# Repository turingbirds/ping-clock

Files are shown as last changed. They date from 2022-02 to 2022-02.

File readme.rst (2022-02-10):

The Ping Clock
==============

Are you ever in a video call, when the other party suddenly freezes mid-sentence, leaving you wondering after a few seconds of silence: is it my connection that's having issues, or theirs? In such situations, one glance at the ping clock dial provides an immediate overview of your internet connection status and health, measured in terms of ping time.

Ping time is the time it takes for a network packet to reach a certain destination host and come back again. Lower is better; for video calls, anything below a few tenths of a second is typically fine. The host can be chosen as a public server with high reliability (for example, google.com or 80.80.80.80), or as something with a special significance (like the hostname of your cloud instance).

If your video call freezes, but the ping clock continues to indicate low ping, there is no need to reset your router; just wait for the other side to come back.

.. table::
   :align: center

   +-------------------------------------------------------------------------------------------------------------------------------------------------------------+
   | 🢧  `Click here for a video of the ping clock in action <https://github.com/turingbirds/ping-clock/blob/master/fig/ping_clock_movie.mp4?raw=true>`_        🢠 |
   +-------------------------------------------------------------------------------------------------------------------------------------------------------------+

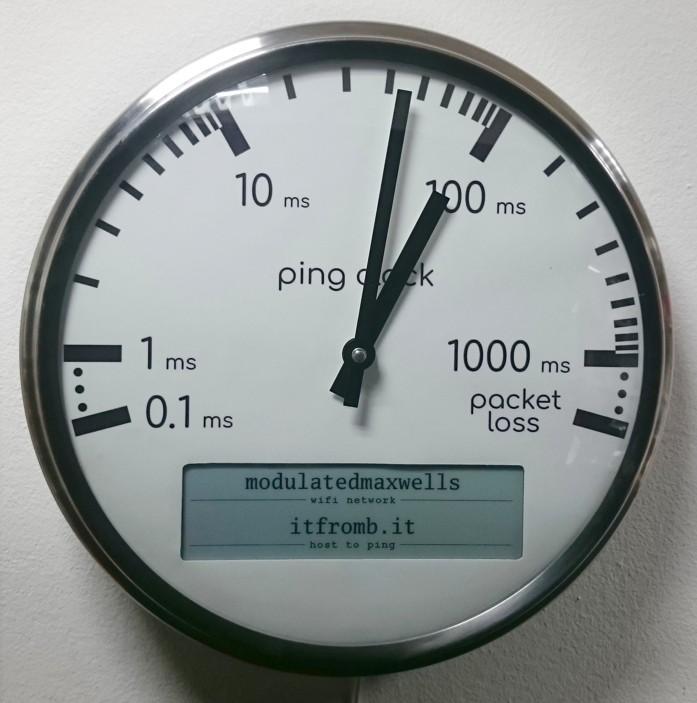
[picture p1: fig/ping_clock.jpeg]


Setting up the wifi network and host to ping is done by connecting to the ping clock's wifi access point. After configuration, the outermost hand will update once each second with the latest ping value, while the innermost hand tracks the recent maximum pings, making an intermittent connection easy to see.





.. table::
   :align: center

   +---------------+---------------+
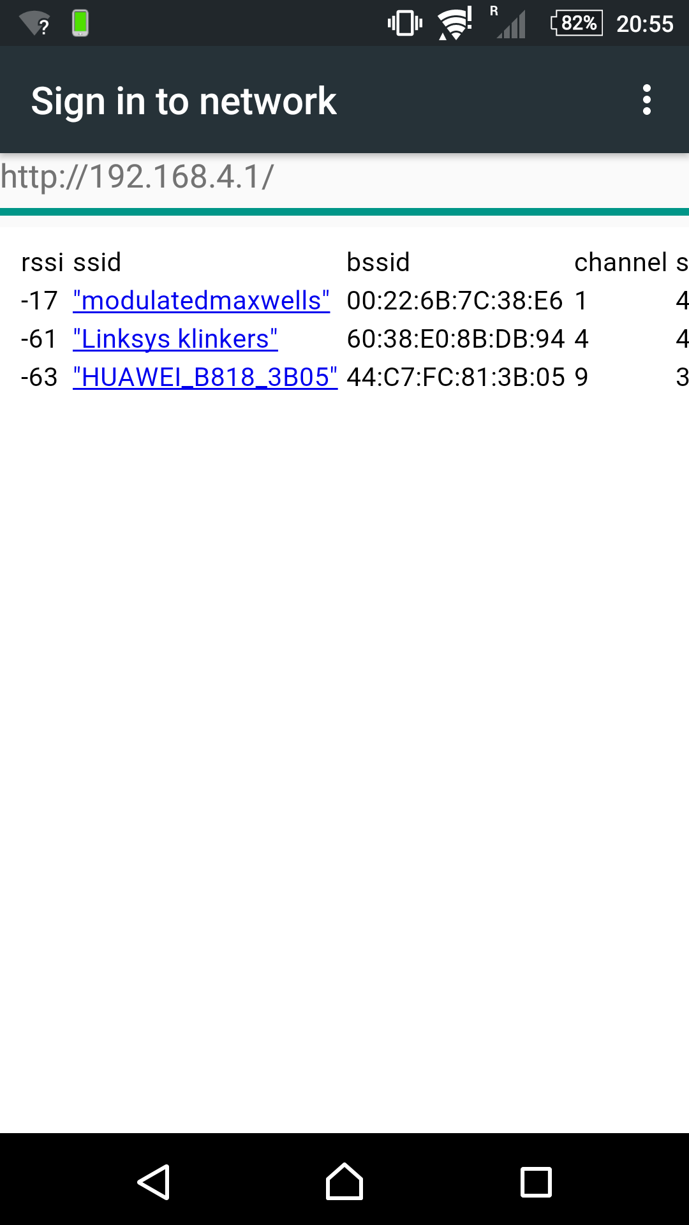
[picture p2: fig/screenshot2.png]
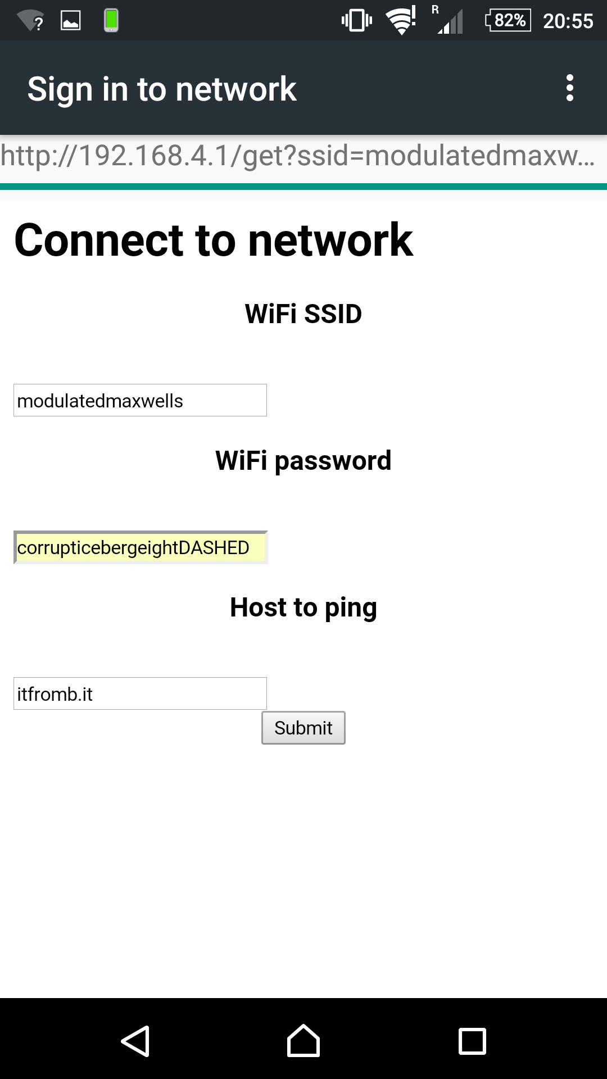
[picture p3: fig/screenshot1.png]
   |  |  |
   +---------------+---------------+

Hardware
--------

The system is controlled by an ESP32, which connects via wifi and updates the e-paper display, and then performs the ping, computes the desired clock hand angles, and sends this angle via SPI to a second ESP32, which functions exclusively as a motor controller.

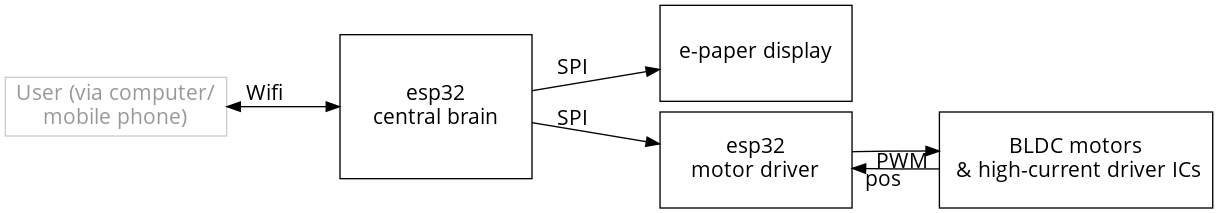
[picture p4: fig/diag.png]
System block diagram


For mounting the components to the frontplate, a template is provided in `frontplate-cad/frontplate_cnc.pdf <https://github.com/turingbirds/ping-clock/blob/master/frontplate-cad/frontplate_cnc.pdf>`_. Drill out all the holes marked in pink, then drill out all the M3 screw holes at half depth in a larger diameter, to create holes for the countersunk screw heads. The frontplate decal then lies flat against the front, covering all the screws. The front of the e-paper display is pressed against the back of the faceplace, held in place by two aluminium bars covered in a layer of foam.
   
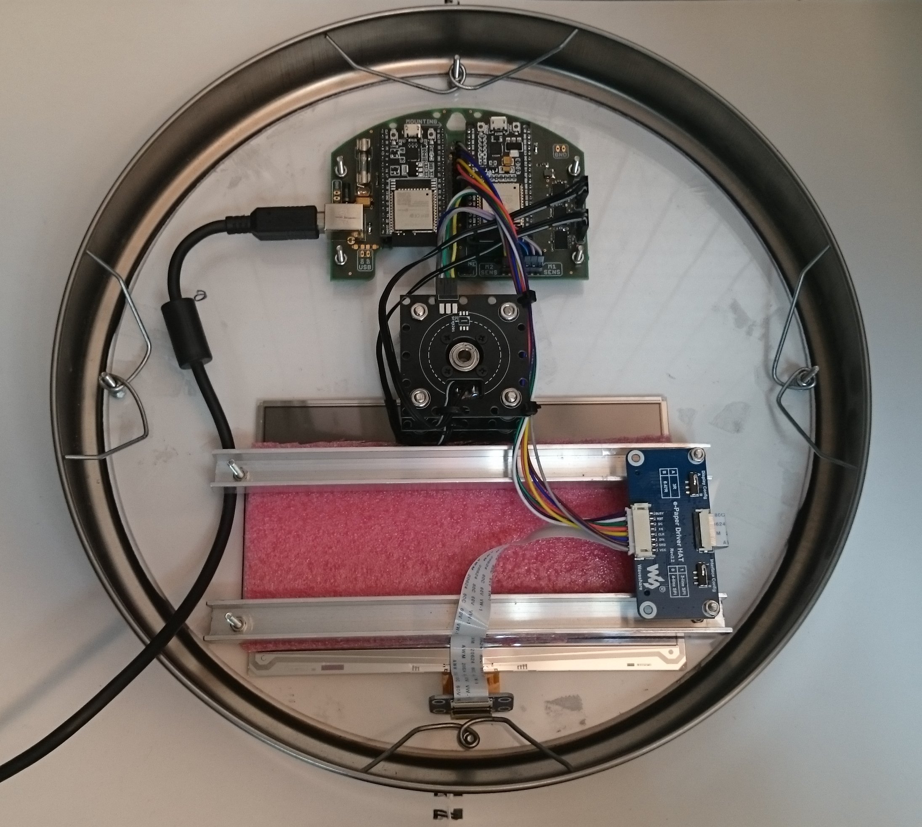
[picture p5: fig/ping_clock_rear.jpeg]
Rear view of the ping clock


The clock is powered from a 5 V DC supply, and consumes approximately 2 W of power. The ESP32s and motor driver ICs are mounted on a custom PCB (see `pcb/ping_clock_mounting_pcb.* <pcb/>`_). 

Dual clock hands motor module
~~~~~~~~~~~~~~~~~~~~~~~~~~~~~

Each hand is actuated by a three-phase brushless DC (BLDC) motor. Actuation is 'direct drive': the hands are mounted directly onto the rotating surface of the motors via two 3D printed hubs.

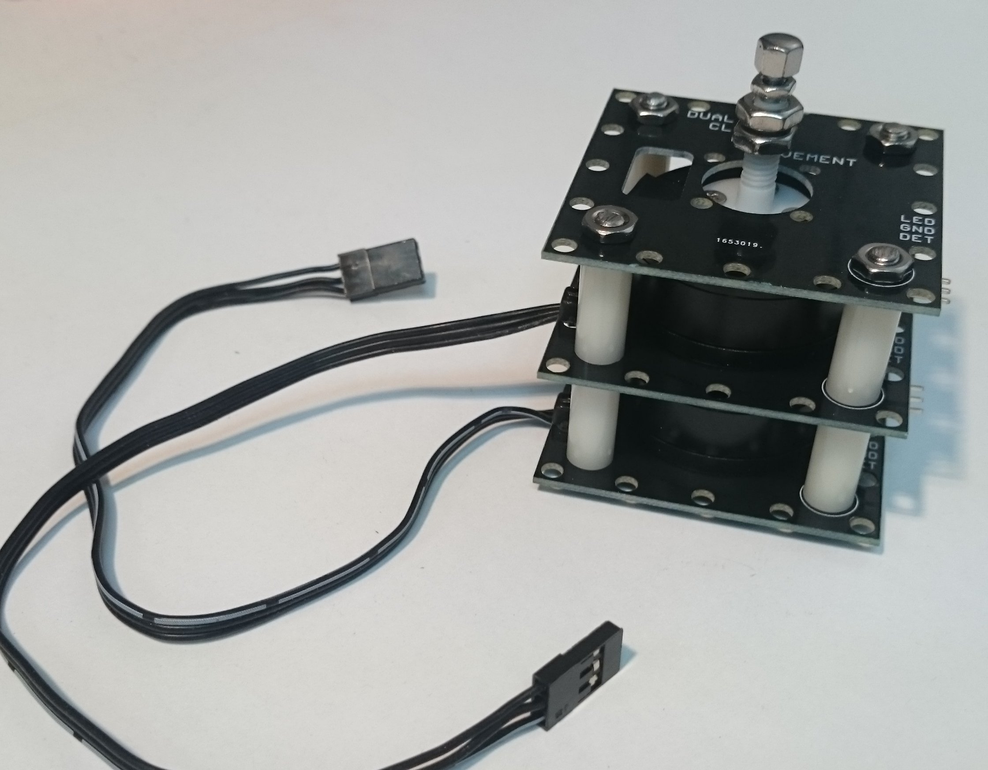
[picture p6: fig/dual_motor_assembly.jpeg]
The dual motor assembly by itself


BLDC motors can be easily controlled as open-loop servos (akin to stepper motors), with reliable tracking over long timescales provided that the load torque is minimal and that acceleration is bounded. An optical reflection light sensor provides an absolute reference point or 'zero angle'. The motor controller ESP32 generates three-channel PWM drive signals for each motor, following a trapezoidal commutation scheme.

PCBs are 1.2 mm, with black solder mask to reduce ambient light for the optical sensors. All three PCBs (`pcb/motor_module_pcb.* <pcb/>`_) are identical, but only two of them need to have a reflection sensor mounted. The dimensions (width x depth x height) of the assembly, ignoring the protruding hubs, is 50 x 50 x 44 mm. The height is 2 * 18 (spacers) + 3 * 1.2 (PCBs) + 2 * 2.2 (thin M4 nuts) = 44 mm.

Hubs
~~~~

The hubs can be 3D printed using the stereolithographic (resin/UV) method. The outer hub is shown first and contains an outer M5 thread to facilitate mounting the corresponding hand. It has a hollow core, which allows the threaded rod of the inner hand assembly to pass through.

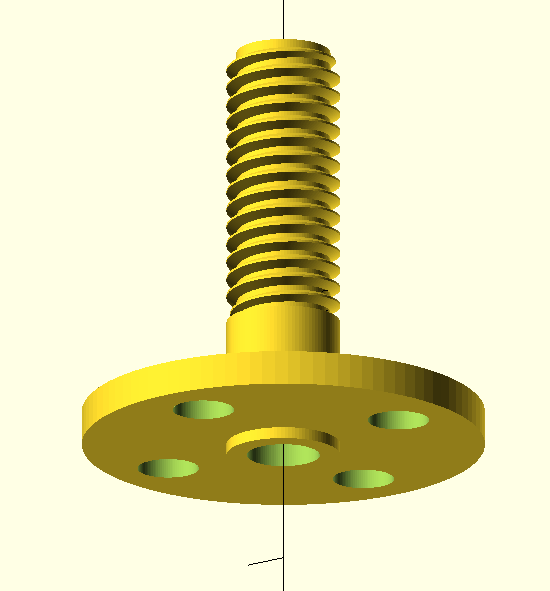
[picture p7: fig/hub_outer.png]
3D view of the outer hub in OpenSCAD


The inner hub provides an inner M3 thread, that seats a short section of threaded rod, which sticks through the other hub and to the front of the clock faceplate.

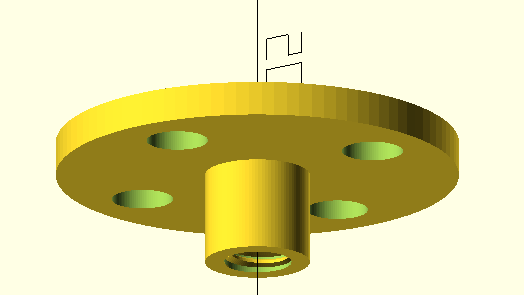
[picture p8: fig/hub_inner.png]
3D view of the inner hub in OpenSCAD


The hands are mounted using the threads provided:

- Central axis: M3 (3 mm diameter) threaded rod

  The hand is pressed between a thin M3 nut and an M3 capped nut.

- Hub axis: M5 (5 mm diameter), threaded
  
  The hand is pressed between two thin M5 nuts. A single M5 rivet could potentially also be used, extending into the clock, to reduce the height that is necessary above the faceplate.

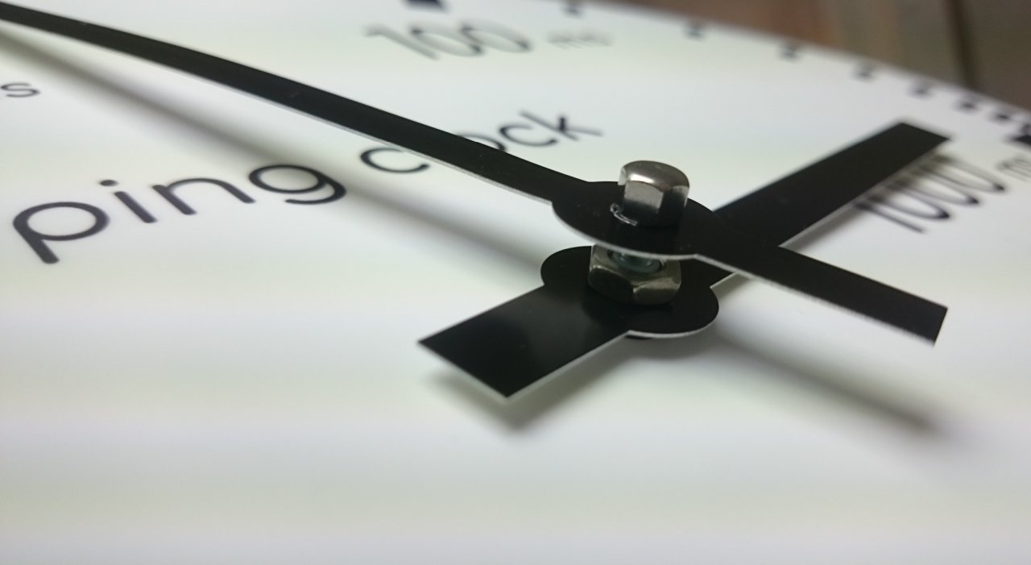
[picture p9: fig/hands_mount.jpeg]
Mounting the clock hands


It is advisable to post-process the 3D printed threads by going over the threads with an M3 and M5 tap, and to drill out the hollow core on the outer hub using a 3.2 mm drill.

Frontplate
~~~~~~~~~~

The frontplate is made out of polycarbonate, in a circular shape, thickness = 4 mm, diameter = 275 (visible portion) + 2*7.5 (behind the metal rim on either side) = 290 mm.

The frontplate graphics can be printed on A3 size paper. A better alternative is to get it as a vinyl sticker.

Note that not all of the display pixels are visible with the current cutout dimensions. This is by design, but you can make the cutout larger to reveal a larger area of the display.

Rim
~~~

Reused from Ikea clock, diameter = 275 mm (dial), 300 mm (overall).

Bill of materials
-----------------

Hardware
~~~~~~~~

(shipping costs excluded)

.. csv-table:: Bill of materials
   :header: "€", "Description"

   "57.19", "7.5"", 800x480 pixel e-paper display https://www.waveshare.com/w/upload/6/60/7.5inch_e-Paper_V2_Specification.pdf"
   "14.92", "Frontplate https://kunststofplatenshop.nl/product/polycarbonaat-helder-4-mm/"
   "6.20", "TB6612FNG motor driver IC (qty: 3)"
   "4", "SFH9201 optical sensor (qty: 2)"
   "7.71", "motor assembly PCBs, color: black, thickness: 1.2mm (seeedstudio; qty: 3)"
   "1.66", "3D printing of the hubs (dirtypcbs.com)"
   "5", "System PCB, color: any, thickness: 1.6 mm (seeedstudio)"
   "14", "frontplate laser-cut vinyl sticker (note: printing this on A3 size paper and cutting it out by hand is a cheaper alternative)"
   "0.10", "motor position sticker (qty: 2)"
   "1", "screws 2mm flat head (qty: 8)"
   "1", "screws 2.5mm flat head (qty: 8)"
   "1", "screws 3mm countersunk head (qty: 16)"
   "1", "M3 nut (qty: 36)"
   "1", "thin M4 nut (qty: 8)"
   "0.50", "M3 threaded rod"
   "1", "M4 threaded rod"
   "0.10", "thin M5 nut (qty: 2)"
   "0.10", "thin M3 nut"
   "0.10", "M3 capped nut"
   "0.55", "vinyl spacer, h = 18 mm, inner d = 4 mm, outer d = 7 mm (qty: 8)"
   "13.69", "BLDC motor with hollow axis (qty: 2)"
   "7.14", "ESP32-DEVKIT (qty: 2)"
   "1", "USB-A PCB mount connector"
   "1", "500 mA fuse and holder"
   "1", "0.1"" IDC headers"
   "1", "0.1"" IDC cables"
   "0.10", "470 R resistor 1206 (qty: 3)"
   "0.10", "47k R resistor 1206 (qty: 2)"
   "0.10", "100 nF capacitor 1206 (qty: 10)"
   "0.10", "10 uF tantal capacitor SMD"
   "5", "Ikea clock (second hand, for the rim and glass)"
   "", ""
   "148.36", "**Total**"

Software
~~~~~~~~

Comfortaa font <aajohan@gmail.com> SIL Open Font License, Version 1.1

Luxi font copyright (c) 2001 by Bigelow & Holmes Inc.

Ping code from https://github.com/marian-craciunescu/ESP32Ping (LGPL-2.1 license).

log2fix code from https://github.com/dmoulding/log2fix (MIT license).

Credits
-------

With gratitude to `Jan Breemer <http://www.breem.nl/>`_ for debugging the 3D model of the hubs and help with the prototype!

License
-------

`Open source hardware <https://www.oshwa.org/>`_ is hardware for which the design is made publicly available, so that anyone can study, modify, distribute, make, and sell the design or hardware based on that design, subject to the following license conditions.

Hardware licensed under the *CERN Open Hardware Licence Version 2 - Weakly Reciprocal,* a copy of which is included in this repository at `cern_ohl_w_v2.txt <https://github.com/turingbirds/ping-clock/blob/master/cern_ohl_w_v2.txt>`_.

Software licensed under the *Apache License 2.0,* a copy of which is included at `apache_license_2.0.txt <https://github.com/turingbirds/ping-clock/blob/master/apache_license_2.0.txt>`_.

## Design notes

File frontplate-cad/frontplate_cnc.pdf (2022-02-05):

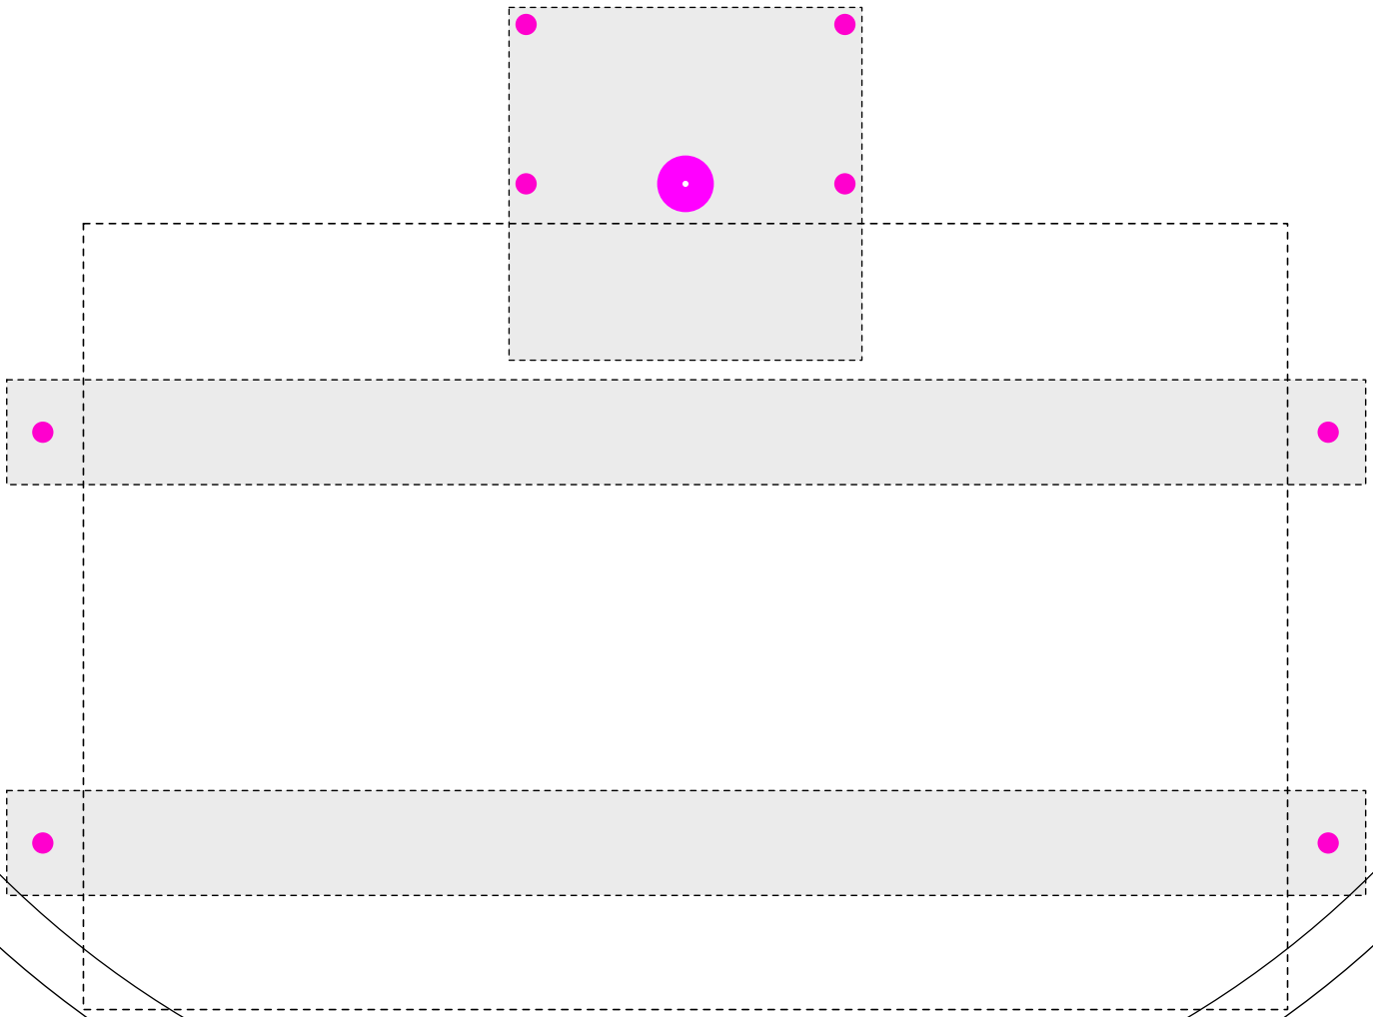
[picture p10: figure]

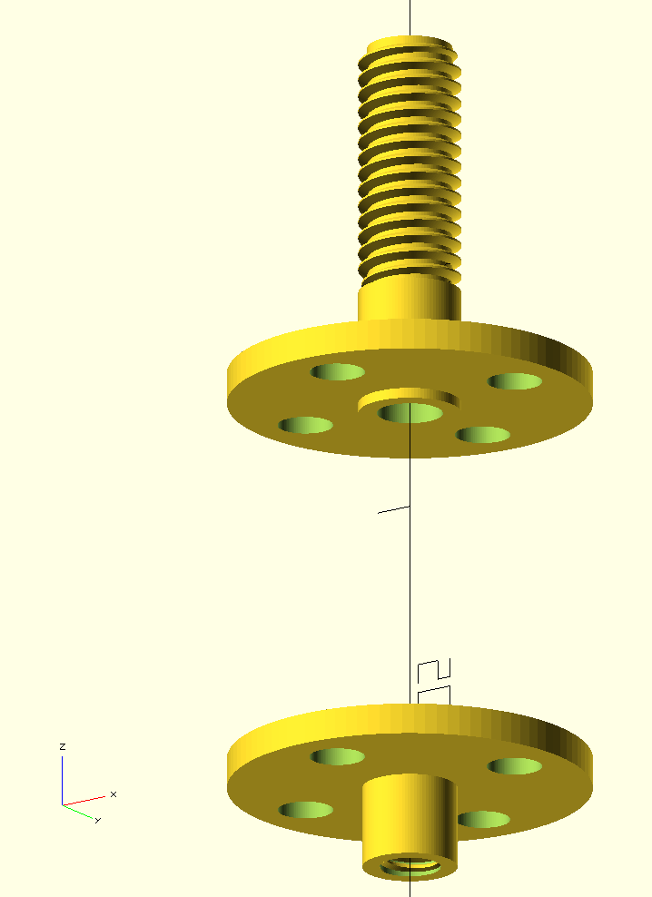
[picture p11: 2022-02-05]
fig/hubs.png

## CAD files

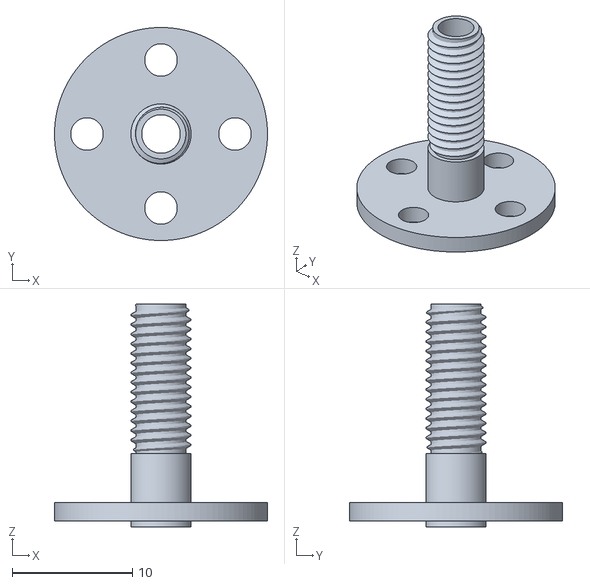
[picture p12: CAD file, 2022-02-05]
dual_bldc_assembly/outer_hub.stl
17.7 x 17.7 x 18.5

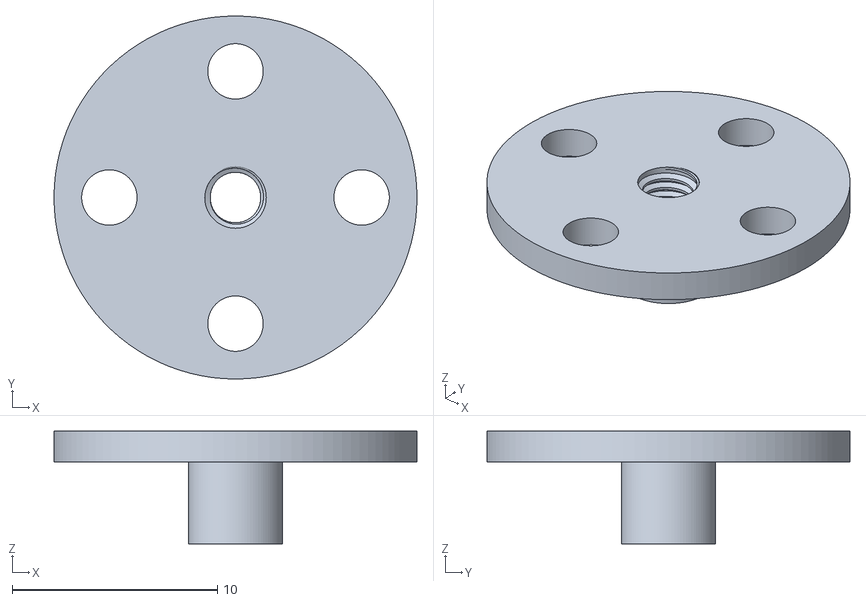
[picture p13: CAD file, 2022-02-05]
dual_bldc_assembly/inner_hub.stl
17.7 x 17.7 x 5.50

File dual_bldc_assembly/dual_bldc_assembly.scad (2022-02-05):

/**

Charl Linssen <charl@itfromb.it>, December 2021

Inner hub needs to tapped internally at M3 to accept threaded rod. Rod is secured to the hub by one additional nut on top of the hub (towards the front of the clock face).

Outer hub needs to be tapped externally (at the front of the clock) at M5 to allow clock hand to be mounted (clamped between two thin M5 nuts).

**/

include <NopSCADlib/core.scad>
use <NopSCADlib/utils/thread.scad>


/**
 * OpenSCAD rendering parameters
**/

pi = 3.14159;

quality_factor = 10;

$fn = quality_factor * 10;
$fn2 = quality_factor * 10;

bevel_resolution = quality_factor;


/**
 * which parts to draw (set to 0 or 1)
**/

draw_motors = 0;
draw_mounting = 0;


/**
 * margins
**/

epsilon = .1; // [mm]
motor_axis_insert_margin = .1; // [mm]


/**
 * model parameters for BLDC motors
**/

r_eccentr_holes_bldc_stator = 19.1/2;  // [mm]
r_eccentr_holes_bldc_rotor = 12.3/2;  // [mm]
n_holes_bldc_stator = 4;
deg_per_hole = 360/n_holes_bldc_stator;
D_bldc_motor = 34.56; // diameter of the motor itself [mm]
h_bldc_motor = 14.22; // height of the motor itself [mm]
D_bldc_motor_cutout = 5; // diameter of the hollow axis of the BLDC motor [mm]
D_bldc_rotor_cutout = 15;  // cutout of the mounting plane for the rotor+hub to pass through [mm]


/**
 * model parameters for the hubs
**/

hub_base_thickness = 1.5; // [mm]
D_bldc_stator_holes = 2.7;   // diameter of the holes for mounting it to the motor [mm] (screw thread is M2.5)

h_outer_hub = 18; // [mm]
D_outer_hub_outer = 5; // diameter of the outer clock hand [mm]

h_inner_hub = 37; // [mm]
D_inner_hub_outer = 3; // diameter of the inner clock hand [mm]

inner_hub_h_motor_insert = 4; // length by which the rear end of the rotating plate sticks into the motor
outer_hub_h_motor_insert = .5; // length by which the rear end of the rotating plate sticks into the motor

outer_hub_thread_height = 12.5;


/**
 * model parameters for mounting plane standoffs
**/

h_standoffs = 18; // [mm]

D_standoffs_inner = 4; // [mm]
D_standoffs_outer = 7; // [mm]
r_ecc_standoffs = 25; // [mm]

h_thin_M4_nut = 2.1;  // [mm]
r_hub_cutout = 15/2; // [mm] XXX: was 4

z_second_platform = hub_base_thickness + h_standoffs;


// ----------------------------------------------------------------------------------------------------


/**
 * inner hub
**/

color([.5, .7, .7])
translate([0., 0., hub_base_thickness + h_bldc_motor])
union() {
    // base
    difference() {
        union() {
            cylinder(h=hub_base_thickness, r=r_eccentr_holes_bldc_rotor + D_bldc_stator_holes);

            // part that sticks out the back
            translate([0,0,-inner_hub_h_motor_insert])
            cylinder(h=inner_hub_h_motor_insert + epsilon, r=D_bldc_motor_cutout/2 - motor_axis_insert_margin);
        }
        
        union() {
            translate([0, 0, -inner_hub_h_motor_insert - epsilon])
            cylinder(h=inner_hub_h_motor_insert + h_inner_hub + 2*epsilon, r=D_inner_hub_outer/2 + 2*epsilon);   // XXX: slight bit of extra cutout for the thread

            // holes for rotor mounting screws
            for (hole_idx = [0:(n_holes_bldc_stator-1)]) {
                rotate(a=hole_idx * deg_per_hole, v=[0, 0, 1])
                translate([0., r_eccentr_holes_bldc_rotor, -epsilon])
                cylinder(h=hub_base_thickness + 2*epsilon, r=D_bldc_stator_holes/2);
            }
        }
    }
    translate([0, 0, -inner_hub_h_motor_insert+ (inner_hub_h_motor_insert + hub_base_thickness) / 2])
    female_metric_thread(3, metric_coarse_pitch(3), inner_hub_h_motor_insert + hub_base_thickness);
}


/**
 * outer hub
**/

color([.3, .5, .7])
translate([0., 0., z_second_platform + hub_base_thickness + h_bldc_motor])
difference() {
    union() {
        cylinder(h=h_outer_hub, r=D_outer_hub_outer/2 - .43);

        intersection() {
            difference() {
                translate([0., 0., outer_hub_thread_height/2 + h_outer_hub - outer_hub_thread_height])
                male_metric_thread(5, metric_coarse_pitch(5), outer_hub_thread_height);
        
                cylinder(h=h_outer_hub, r=D_outer_hub_outer/2 - .43 - 2 * epsilon);
            }
            cylinder(h=h_outer_hub, r=D_outer_hub_outer*2);
        }

        cylinder(h=h_outer_hub - outer_hub_thread_height + epsilon, r=D_outer_hub_outer/2);

        // part that sticks out the back
        translate([0,0,-outer_hub_h_motor_insert])
        cylinder(h=outer_hub_h_motor_insert + epsilon, r=D_bldc_motor_cutout/2 - motor_axis_insert_margin);
       
        // base
        difference() {
            cylinder(h=hub_base_thickness, r=r_eccentr_holes_bldc_rotor + D_bldc_stator_holes);

            union() {
                // holes for rotor mounting screws
                for (hole_idx = [0:(n_holes_bldc_stator-1)]) {
                    rotate(a=hole_idx * deg_per_hole, v=[0, 0, 1])
                    translate([0., r_eccentr_holes_bldc_rotor, -epsilon])
                    cylinder(h=hub_base_thickness + 2*epsilon, r=D_bldc_stator_holes/2);
                }
            }
        }

        if (draw_mounting) {
            /**
             * mounting screw heads
            **/

            for (hole_idx = [0:(n_holes_bldc_stator-1)]) {
                rotate(a=hole_idx * deg_per_hole, v=[0, 0, 1])
                translate([0., r_eccentr_holes_bldc_rotor, hub_base_thickness+.02])
                cylinder(h=1, r=2); // screw head height: 1mm, dia: 4mm
            }
        }
    }

    // cutout for the inner hub
    translate([0, 0, -h_outer_hub])
    cylinder(h=3*h_outer_hub, r=D_inner_hub_outer/2 + epsilon);
}

    
/**
 * PCBs, mounting, screws, etc.
**/

if (draw_mounting) {

    /**
     * mounting planes for BLDCs
    **/

    for (motor_idx = [0:2]) {
        translate([0., 0, motor_idx*z_second_platform])
        difference() {
            translate([0, 0, hub_base_thickness/2])
            cube([50,50,hub_base_thickness], center=true);

            union() {
                if (motor_idx < 2) {
                    // holes for mounting screws
                    for (hole_idx = [0:(n_holes_bldc_stator-1)]) {
                        rotate(a=hole_idx * deg_per_hole, v=[0, 0, 1])
                        translate([0., r_eccentr_holes_bldc_stator, -epsilon])
                        cylinder(h=hub_base_thickness + 2*epsilon, r=D_bldc_stator_holes/2);
                    }
                    // central rotor cutout hole
                    translate([0., 0., -epsilon])
                    cylinder(h=hub_base_thickness + 2*epsilon, r=D_bldc_rotor_cutout/2);
                }
                else {
                    // central rotor cutout hole
                translate([0., 0., -epsilon])
                cylinder(h=hub_base_thickness + 2*epsilon, r=r_hub_cutout);
                }
            }
        }
    }

        // mounting screw heads
        for (hole_idx = [0:(n_holes_bldc_stator-1)]) {
            rotate(a=hole_idx * deg_per_hole, v=[0, 0, 1])
            translate([0., r_eccentr_holes_bldc_stator, hub_base_thickness+.1])
    translate([0., 0, 2*z_second_platform-2.62])
            cylinder(h=1, r=2); // screw head height: 1mm, dia: 4mm
        }


    /**
     *  holes for mounting screws
    **/

    %
    for (z = [0:z_second_platform]) {
        for (hole_idx = [0:(n_holes_bldc_stator-1)]) {
            rotate(a=hole_idx * deg_per_hole + 45, v=[0, 0, 1])
            translate([0., -r_ecc_standoffs, z + hub_base_thickness])
            cylinder(h=h_standoffs, r=D_standoffs_outer/2);
        }
    }

    /**
     *  photo switches
    **/

    h_photo_switch = 2.1;

    rotate(a=45, v=[0, 0, 1])
    union() {
        translate([-12.5, 0, 37.5])
        cube([3.4, 4.2, h_photo_switch], center=true);

        translate([0., 0, z_second_platform])
        translate([-12.5, 0, -h_photo_switch/2 - .1])
        cube([3.4, 4.2, h_photo_switch], center=true);
    };
}

/**
 * BLDC motors 
**/

if (draw_motors) {
    for (motor_idx = [0:1]) {
        translate([0., 0, hub_base_thickness + motor_idx*z_second_platform])
        difference() {
        color([1,0,0],.2)
            cylinder(h=h_bldc_motor, r=D_bldc_motor/2);
             
            translate([0., 0, -epsilon])
            cylinder(h=h_bldc_motor + 2*epsilon, r=D_bldc_motor_cutout/2);
        }
    }
}

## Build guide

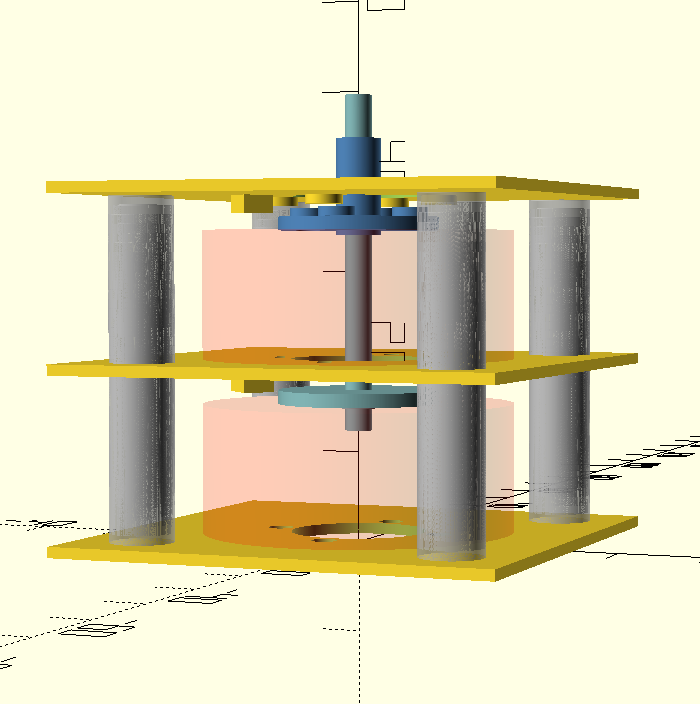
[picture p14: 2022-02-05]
fig/dual_motor_assembly.png

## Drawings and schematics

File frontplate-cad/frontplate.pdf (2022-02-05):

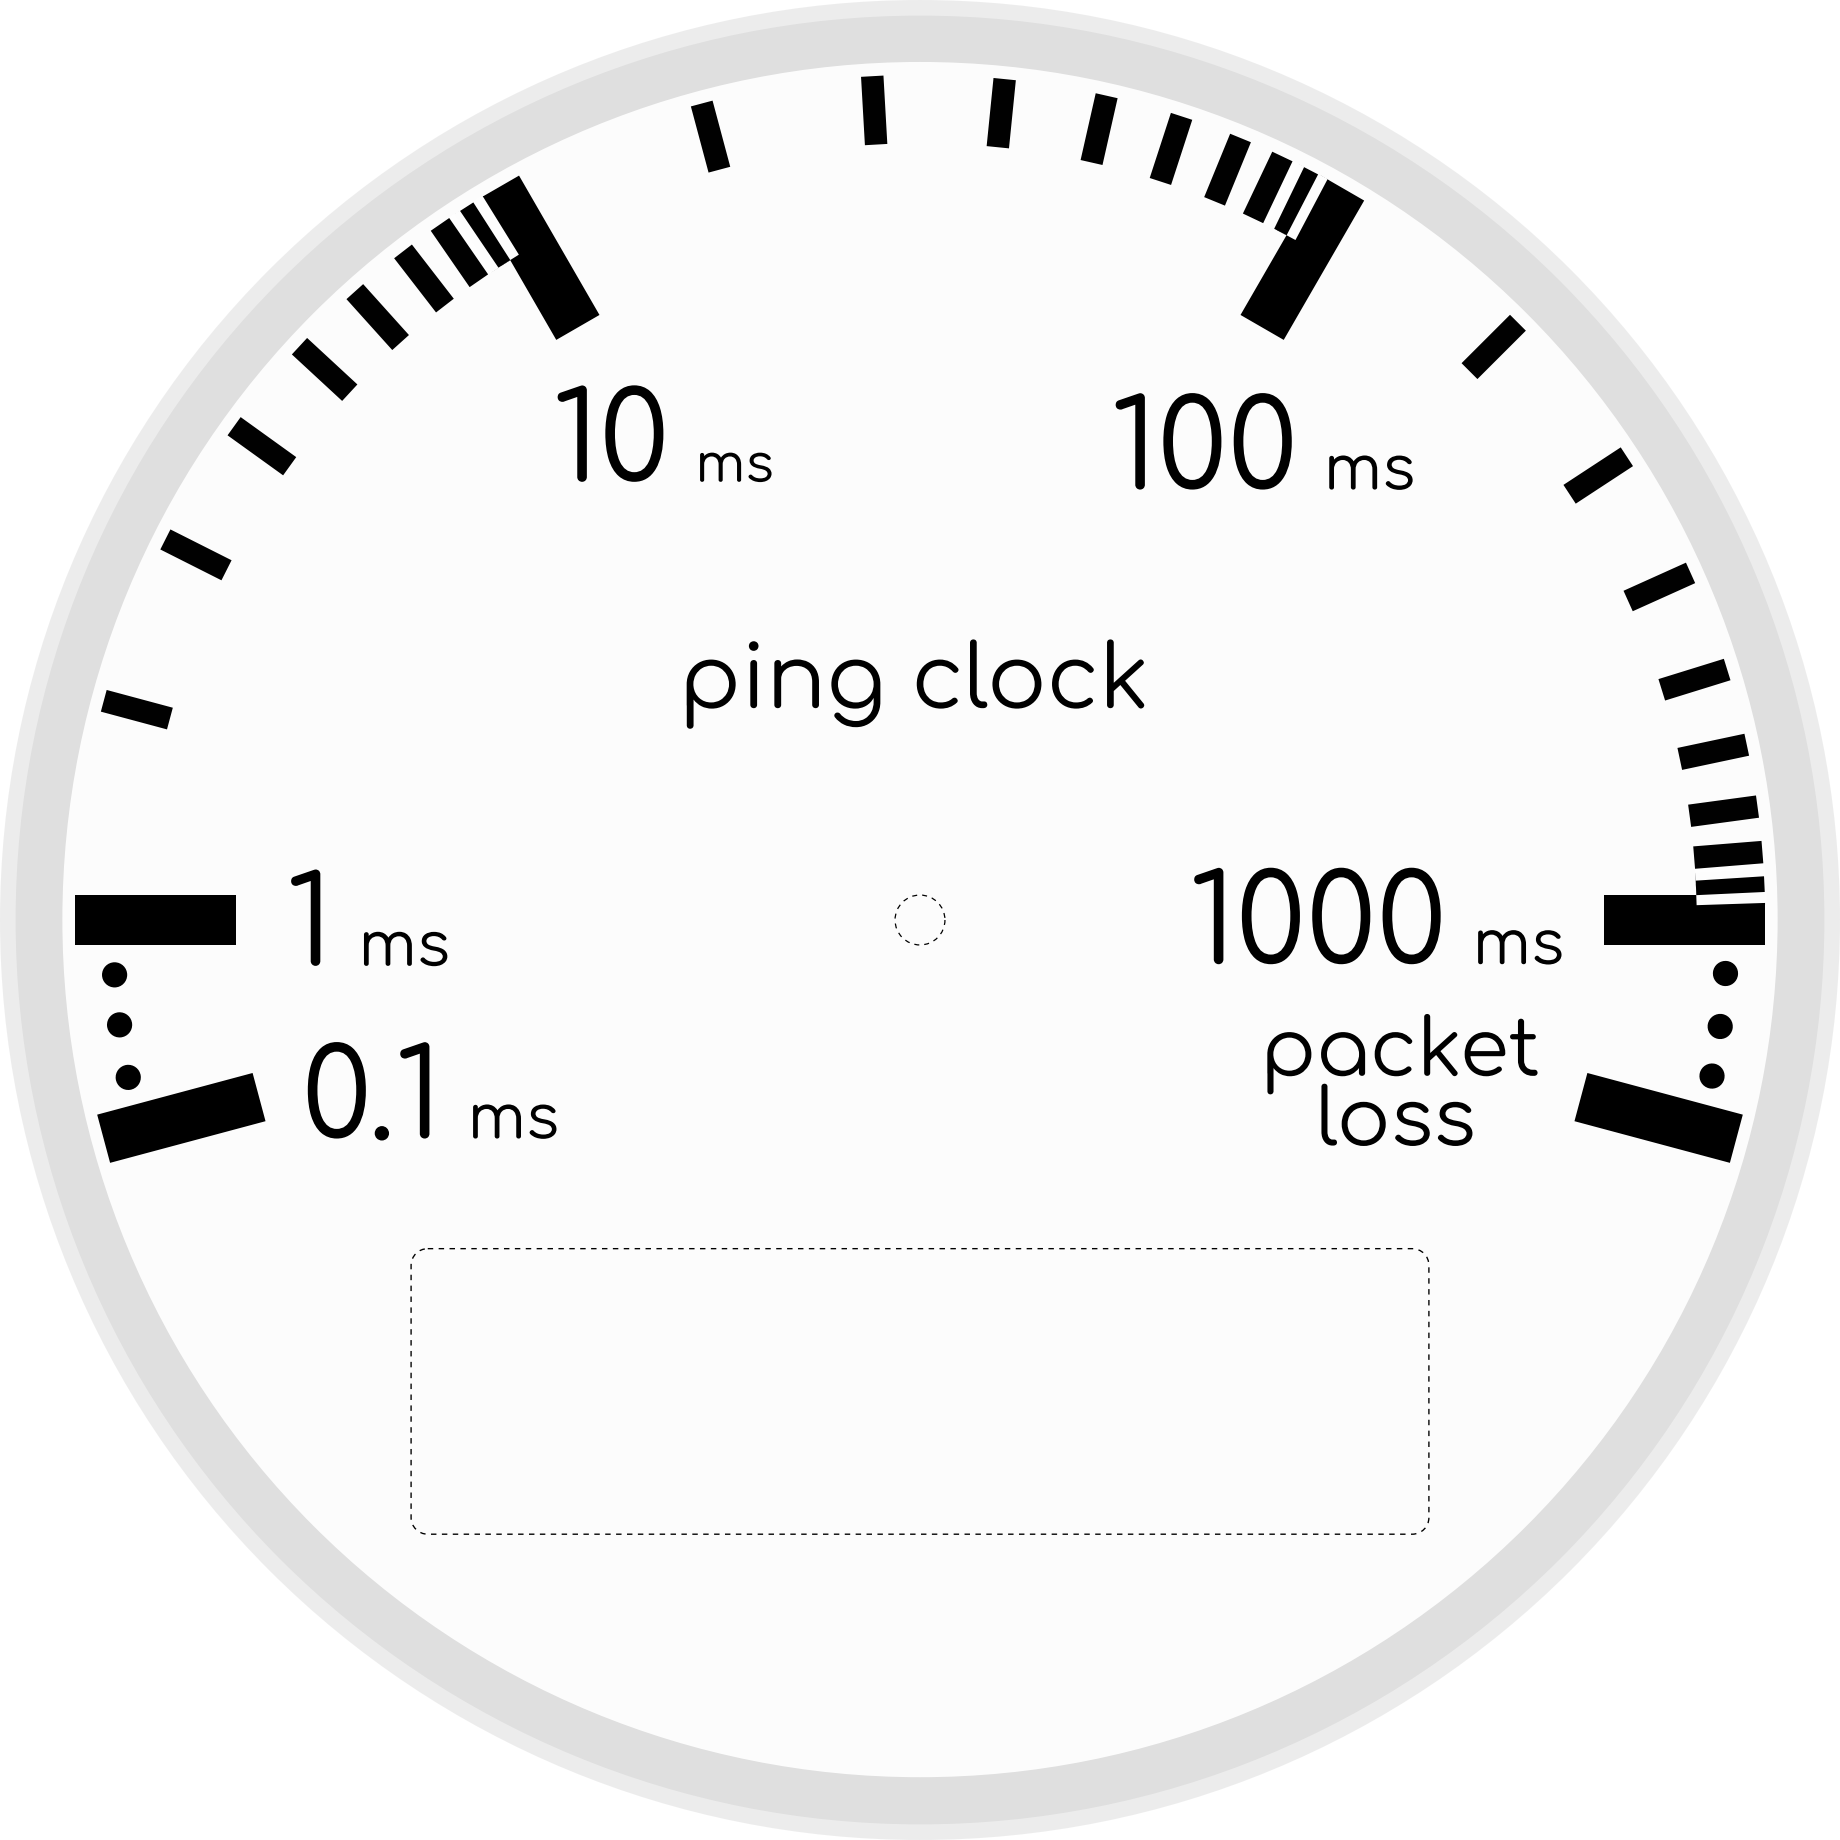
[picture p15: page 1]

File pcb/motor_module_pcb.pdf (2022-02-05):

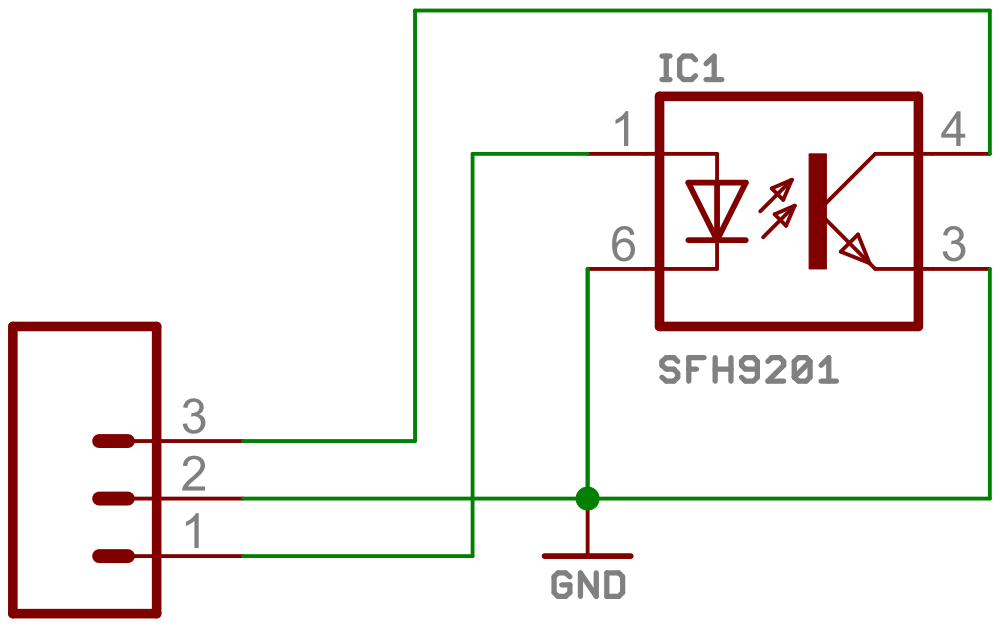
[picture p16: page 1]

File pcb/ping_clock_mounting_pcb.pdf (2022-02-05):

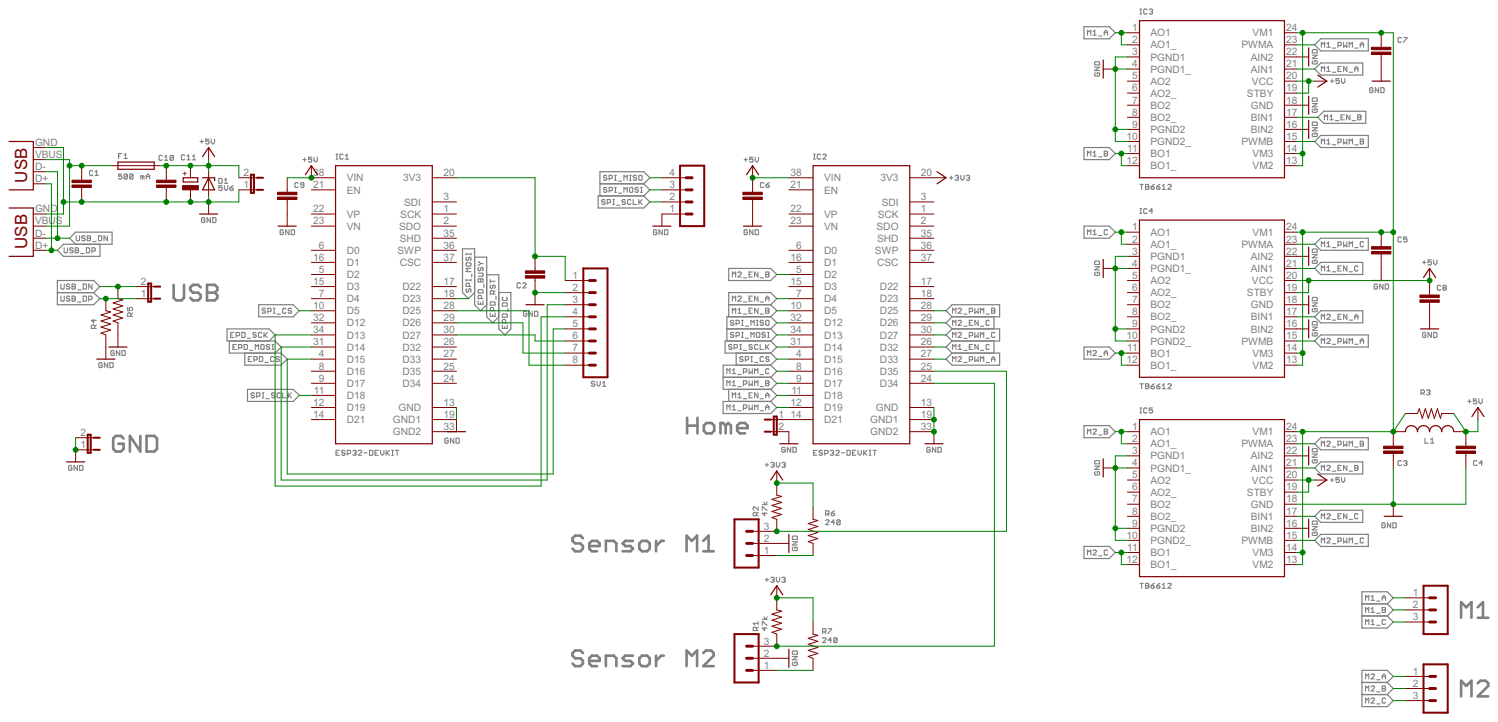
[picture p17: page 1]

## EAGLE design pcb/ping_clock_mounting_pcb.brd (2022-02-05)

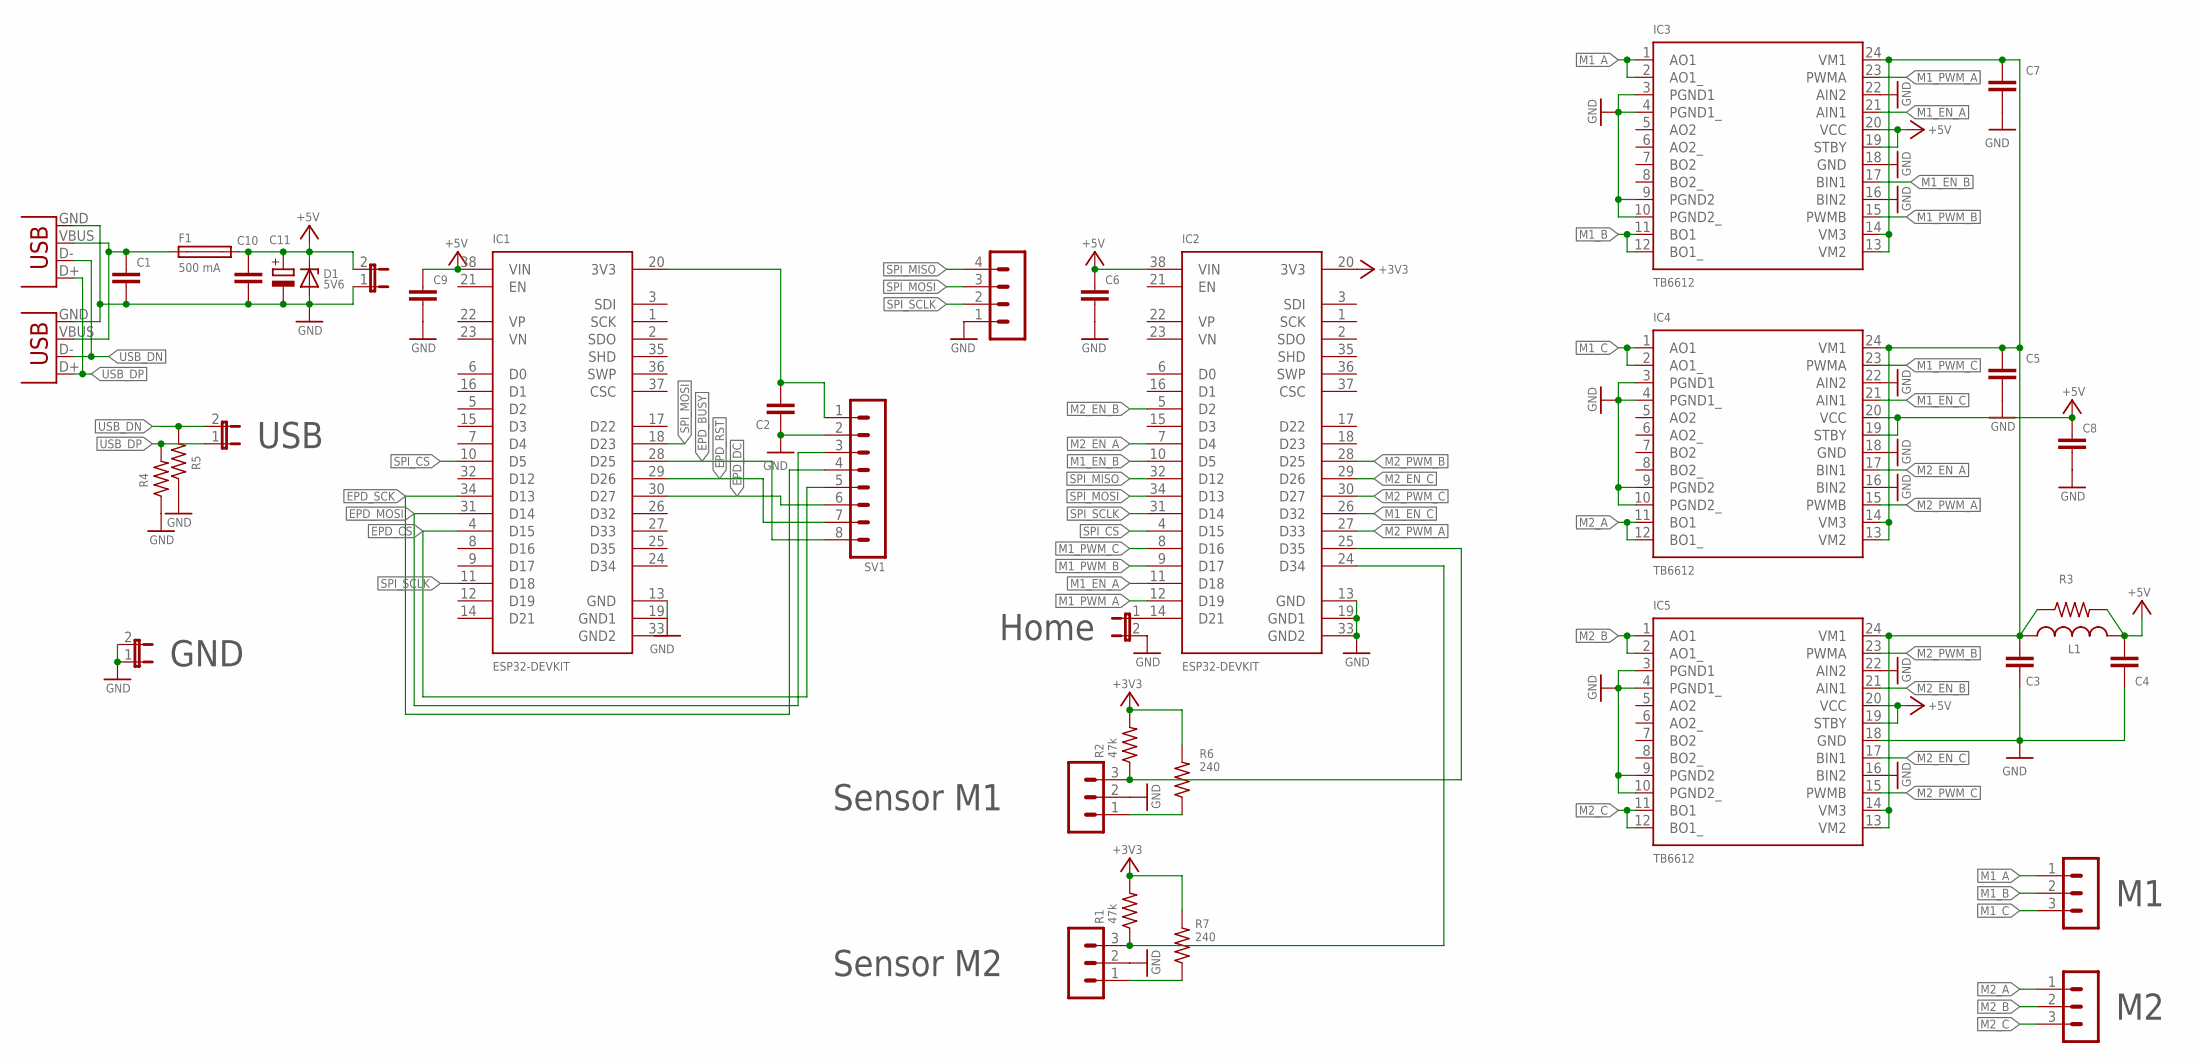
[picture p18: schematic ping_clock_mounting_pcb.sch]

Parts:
C1, C2, C3, C4, C5, C6, C7, C8, C9, C10: C-EUC1206; C1206
C11: CPOL-EUD/7343-31R; D/7343-31R
D1: 5V6; DO41Z10
F1: 500 mA; SHK20L
IC1, IC2: ESP32-DEVKIT; MODULE_ESP32_DEVKIT_V1
IC3, IC4, IC5: TB6612; SSOP24
JP1, JP3, JP4, JP5: JP1E; JP1
L1: L-USL3225P; L3225P
R1, R2: 47k; R1206
R3, R4, R5: R-US_R1206; R1206
R6, R7: 240; R1206
SV1: MA08-1
SV2, SV3, SV4, SV5: MA03-1
SV6: MA04-1
X1: USBSMD; USB-MINIB
X2: USBPTH; USB-B-PTH

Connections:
+3V3: IC2.20 (3V3), R1.2, R2.2, R6.2, R7.2
+5V: C4.1, C6.1, C8.1, C9.1, C10.1, C11.+, D1.C, F1.2A (2), IC1.38 (VIN), IC2.38 (VIN), IC3.19 (STBY), IC3.20 (VCC), IC4.19 (STBY), IC4.20 (VCC), IC5.19 (STBY), IC5.20 (VCC), JP5.2, L1.2, R3.2
EPD_BUSY: IC1.28 (D25), SV1.8
EPD_CS: IC1.4 (D15), SV1.5
EPD_DC: IC1.30 (D27), SV1.6
EPD_MOSI: IC1.31 (D14), SV1.3
EPD_RST: IC1.29 (D26), SV1.7
EPD_SCK: IC1.34 (D13), SV1.4
GND: C1.2, C2.1, C3.2, C4.2, C5.2, C6.2, C7.2, C8.2, C9.2, C10.2, C11.-, D1.A, IC1.13 (GND), IC2.13 (GND), IC2.19 (GND1), IC2.33 (GND2), IC3.3 (PGND1), IC3.4 (PGND1_), IC3.9 (PGND2), IC3.10 (PGND2_), IC3.16 (BIN2), IC3.18 (GND), IC3.22 (AIN2), IC4.3 (PGND1), IC4.4 (PGND1_), IC4.9 (PGND2), IC4.10 (PGND2_), IC4.16 (BIN2), IC4.18 (GND), IC4.22 (AIN2), IC5.3 (PGND1), IC5.4 (PGND1_), IC5.9 (PGND2), IC5.10 (PGND2_), IC5.16 (BIN2), IC5.18 (GND), IC5.22 (AIN2), JP1.1, JP1.2, JP4.2, JP5.1, R4.1, R5.1, SV1.2, SV4.2, SV5.2, SV6.1, X1.GND, X2.GND
GND1: IC1.19 (GND1)
GND2: IC1.33 (GND2)
M1_A: IC3.1 (AO1), IC3.2 (AO1_), SV2.1
M1_B: IC3.11 (BO1), IC3.12 (BO1_), SV2.2
M1_C: IC4.1 (AO1), IC4.2 (AO1_), SV2.3
M1_EN_A: IC2.11 (D18), IC3.21 (AIN1)
M1_EN_B: IC2.10 (D5), IC3.17 (BIN1)
M1_EN_C: IC2.26 (D32), IC4.21 (AIN1)
M1_PWM_A: IC2.12 (D19), IC3.23 (PWMA)
M1_PWM_B: IC2.9 (D17), IC3.15 (PWMB)
M1_PWM_C: IC2.8 (D16), IC4.23 (PWMA)
M2_A: IC4.11 (BO1), IC4.12 (BO1_), SV3.1
M2_B: IC5.1 (AO1), IC5.2 (AO1_), SV3.2
M2_C: IC5.11 (BO1), IC5.12 (BO1_), SV3.3
M2_EN_A: IC2.7 (D4), IC4.17 (BIN1)
M2_EN_B: IC2.5 (D2), IC5.21 (AIN1)
M2_EN_C: IC2.29 (D26), IC5.17 (BIN1)
M2_PWM_A: IC2.27 (D33), IC4.15 (PWMB)
M2_PWM_B: IC2.28 (D25), IC5.23 (PWMA)
M2_PWM_C: IC2.30 (D27), IC5.15 (PWMB)
unnamed: IC2.14 (D21), JP4.1
unnamed: C2.2, IC1.20 (3V3), SV1.1
unnamed: C1.1, F1.1A (1), X1.VBUS, X2.VBUS
unnamed: R6.1, SV4.1
unnamed: IC2.24 (D34), R1.1, SV5.3
unnamed: R7.1, SV5.1
unnamed: IC2.25 (D35), R2.1, SV4.3
unnamed: C3.1, C5.1, C7.1, IC3.13 (VM2), IC3.14 (VM3), IC3.24 (VM1), IC4.13 (VM2), IC4.14 (VM3), IC4.24 (VM1), IC5.13 (VM2), IC5.14 (VM3), IC5.24 (VM1), L1.1, R3.1
SPI_CS: IC1.10 (D5), IC2.4 (D15)
SPI_MISO: IC2.32 (D12), SV6.4
SPI_MOSI: IC1.18 (D23), IC2.34 (D13), SV6.3
SPI_SCLK: IC1.11 (D18), IC2.31 (D14), SV6.2
USB_DN: JP3.2, R5.2, X1.D-, X2.D-
USB_DP: JP3.1, R4.2, X1.D+, X2.D+

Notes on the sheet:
Home
Sensor M1
Sensor M2
USB
GND

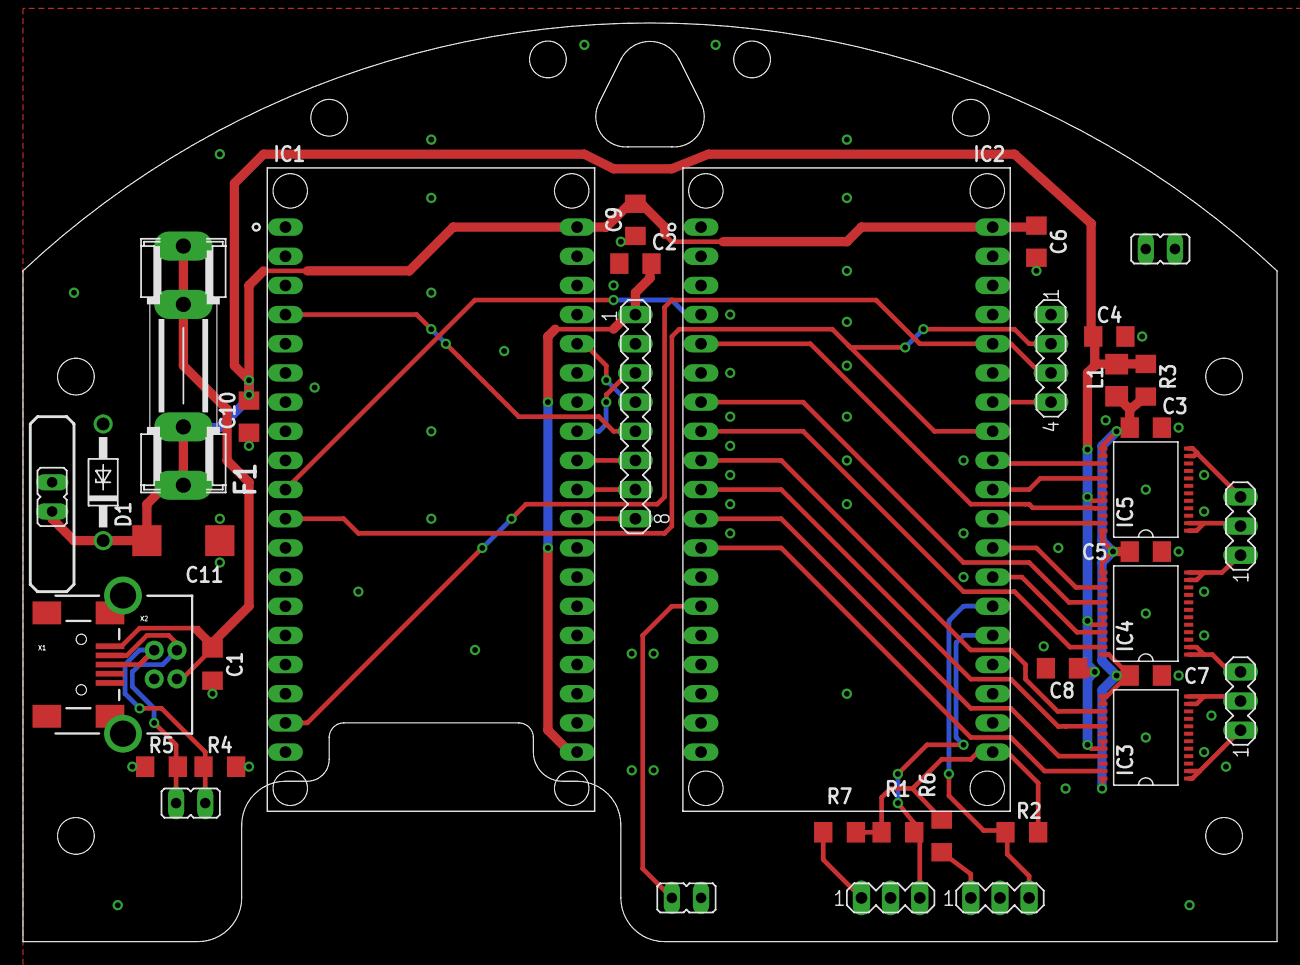
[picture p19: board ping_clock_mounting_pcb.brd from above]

Board: 2 copper layers, 109.2 x 80.0 mm, 38 parts (0 on the bottom side), 41 nets.

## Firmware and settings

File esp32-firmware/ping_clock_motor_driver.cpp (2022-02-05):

/**
 * Ping clock motor driver code
 *
 * https://github.com/turingbirds/ping-clock
**/

// Look out! Enabling serial debug messages will cause the motion to stutter.
//#define SERIAL_DEBUG

#include <stdint.h>
#include <Arduino.h>

#include <math.h>
#include "driver/spi_slave.h"
#include "driver/spi_common.h"


/**
 *    emulate an SPI slave device
**/

#define RCV_HOST    HSPI_HOST

// #define GPIO_MISO 12
#define GPIO_MOSI 13
#define GPIO_SCLK 14
#define GPIO_CS 15

WORD_ALIGNED_ATTR char sendbuf[129]="";
WORD_ALIGNED_ATTR char recvbuf[129]="";

#define DIRECTION_CLOCKWISE 0
#define DIRECTION_COUNTERCLOCKWISE 1
#define DIRECTION_AUTO 2

#define min(a,b) ((a) < (b) ? (a) : (b))
#define max(a,b) ((a) > (b) ? (a) : (b))

volatile uint8_t delay_ = 0;

hw_timer_t * timer = NULL;

const int m1_pwm_a_pin = 19;
const int m1_en_a_pin = 18;
const int m1_pwm_b_pin = 17;
const int m1_en_b_pin = 5;
const int m1_pwm_c_pin = 16;
const int m1_en_c_pin = 32;

const int m2_pwm_a_pin = 33;
const int m2_en_a_pin = 4;
const int m2_pwm_b_pin = 25;
const int m2_en_b_pin = 2;
const int m2_pwm_c_pin = 27;
const int m2_en_c_pin = 26;

const int go_to_zero_pin = 21;

const int photo_interruptor_pin[2] = {35, 34};

const uint8_t MIN_STEPSIZE = 1;
const uint8_t CALIBRATION_STEPSIZE = 12;
const uint8_t MAX_STEPSIZE = 80;

#define SLOWEST_SPEED_TIMER_VAL (320000/(1<<(resolution-4)))
#define FASTEST_SPEED_TIMER_VAL (10000/(1<<(resolution-4)))


/**
 *  geometrical arrangement:
 *
 *  one full rotation consists of ``n_sectors`` sectors
 *  one sector consists of 6 BLDC driving phases
 *  one sector consists of ``max_duty`` steps
**/

const uint8_t n_motors = 2;
const uint8_t n_sectors = 7;   // 7 times through the sine table = 1 full rotation = 360°
const uint8_t n_bldc_phases = 6;
const uint8_t resolution = 12;
const uint16_t max_duty = (1 << resolution) - 1; // 12 bits
const uint32_t max_n_steps = max_duty + max_duty * ((n_bldc_phases-1) + n_bldc_phases * (n_sectors-1));

/**
 *  variables recording absolute position
**/

volatile uint8_t sector[n_motors]; // mod ``n_sectors``
volatile uint8_t bldc_phase[n_motors]; // mod ``n_bldc_phases``
volatile uint16_t phase[n_motors]; // mod ``max_duty``


/**
 *  variables for movement control
**/

volatile int8_t step[n_motors]; // velocity. negative for reverse direction
volatile uint32_t target_n_steps[n_motors];

uint32_t photo_interruptor_angle[n_motors]; // counted in phase ticks
uint8_t photo_interruptor_sector[n_motors];
uint8_t photo_interruptor_bldc_phase[n_motors];
uint16_t photo_interruptor_phase[n_motors];
volatile uint8_t prev_photo_interruptor_pin[2];

// setting PWM properties
const int freq = 25000; // pick this above auditory range! [Hz]
const int m1_pwm_a[n_motors] = {0, 3};
const int m1_pwm_b[n_motors] = {1, 4};
const int m1_pwm_c[n_motors] = {2, 5};


/**
 *  global modes of operation
**/

const uint8_t MODE_CALIBRATE_INIT = 1;
const uint8_t MODE_BALLISTIC_MOVEMENT = 2;
const uint8_t MODE_STOPPED = 0;

volatile uint8_t is_calibrated[n_motors];
volatile uint8_t mode[n_motors];
volatile uint16_t delay_counter = 0;


const float deg_single_sector = 360. / (float)n_sectors;
const float deg_single_bldc_phase = 360. / (float)n_sectors / (float)n_bldc_phases;


// called after a transaction is queued and ready for pickup by master
void my_post_setup_cb(spi_slave_transaction_t *trans) {
}

// called after transaction is sent/received
void my_post_trans_cb(spi_slave_transaction_t *trans) {
}


void init_spi_slave() {
  esp_err_t ret;

  //Configuration for the SPI bus
  spi_bus_config_t buscfg={
      .mosi_io_num=GPIO_MOSI,
      .miso_io_num=-1,
      .sclk_io_num=GPIO_SCLK,
      .quadwp_io_num = -1,
      .quadhd_io_num = -1,
  };

  //Configuration for the SPI slave interface
  spi_slave_interface_config_t slvcfg;
      slvcfg.mode=0;
      slvcfg.spics_io_num=GPIO_CS;
      slvcfg.queue_size=3;
      slvcfg.flags=0;
      slvcfg.post_setup_cb=my_post_setup_cb;
      slvcfg.post_trans_cb=my_post_trans_cb;

  // Enable pull-ups on SPI lines so we don't detect rogue pulses when no master is connected.
  pinMode(GPIO_MOSI, INPUT_PULLUP);
  pinMode(GPIO_SCLK, INPUT_PULLUP);
  pinMode(GPIO_CS, INPUT_PULLUP);

  //Initialize SPI slave interface
  ret = spi_slave_initialize(RCV_HOST, &buscfg, &slvcfg, 0); // DMA disabled
  assert(ret == ESP_OK);
}


void IRAM_ATTR onTimer() {
  for (uint8_t motor_idx = 0; motor_idx < n_motors; ++motor_idx) {

    /**
     * movement state machine
    **/

    if (mode[motor_idx] == MODE_BALLISTIC_MOVEMENT) {
      if (target_n_steps[motor_idx] < abs(step[motor_idx])) {
        // target reached!
        step[motor_idx] = 0;
        mode[motor_idx] = MODE_STOPPED;
      }
      else {
        target_n_steps[motor_idx] -= abs(step[motor_idx]);
      }
    }

    /**
     * calibration state machine
    **/

    if (mode[motor_idx] == MODE_CALIBRATE_INIT) {
      target_n_steps[motor_idx] += abs(step[motor_idx]);
      const uint32_t new_photo_interruptor_pin_analog_value = analogRead(photo_interruptor_pin[motor_idx]);
      if (target_n_steps[motor_idx] > max_n_steps >> 2) { // this condition ensures at least some substantial rotation has happenend before concluding the calibration) {
        if (prev_photo_interruptor_pin[motor_idx] == 0
         && new_photo_interruptor_pin_analog_value > 512) {
          // low-to-high transition
          photo_interruptor_angle[motor_idx] += phase[motor_idx] + max_duty * (bldc_phase[motor_idx] + n_bldc_phases * sector[motor_idx]);
          ++is_calibrated[motor_idx];
        }
        else if (prev_photo_interruptor_pin[motor_idx] == 1
         && new_photo_interruptor_pin_analog_value <= 512) {
          // high-to-low transition
          photo_interruptor_angle[motor_idx] += phase[motor_idx] + max_duty * (bldc_phase[motor_idx] + n_bldc_phases * sector[motor_idx]);
          ++is_calibrated[motor_idx];
        }
      }

      if (is_calibrated[motor_idx] >= 2) {
        photo_interruptor_angle[motor_idx] >>= 1;  // take the average of the two summed terms
        step[motor_idx] = 0;
        mode[motor_idx] = MODE_STOPPED;
      }

      prev_photo_interruptor_pin[motor_idx] = new_photo_interruptor_pin_analog_value > 512 ? 1 : 0;
    }

    if (mode[motor_idx] == MODE_STOPPED) {
      continue;
    }

    /**
     * step through the space (sector, bldc_phase, phase)
    **/

    if (step[motor_idx] > 0 && phase[motor_idx] + step[motor_idx] >= max_duty) {
      phase[motor_idx] = phase[motor_idx] + step[motor_idx] - max_duty;
      if (bldc_phase[motor_idx] == n_bldc_phases - 1) {
        bldc_phase[motor_idx] = 0;
        ++sector[motor_idx];
        if (sector[motor_idx] >= n_sectors) {
          sector[motor_idx] = 0;
        }
      }
      else {
        ++bldc_phase[motor_idx];
      }
    }
    else if (step[motor_idx] < 0 && phase[motor_idx] < -step[motor_idx]) { // phase is pos, step is neg, e.g. phase = 24, step = -32 --> underflow!
      phase[motor_idx] = max_duty + step[motor_idx] + phase[motor_idx];
      if (bldc_phase[motor_idx] == 0) {
        bldc_phase[motor_idx] = n_bldc_phases - 1;
        if (sector[motor_idx] == 0) {
          sector[motor_idx] = n_sectors - 1;
        }
        else {
          --sector[motor_idx];
        }
      }
      else {
        --bldc_phase[motor_idx];
      }
    }
    else {
      phase[motor_idx] += step[motor_idx];
    }

    uint16_t dutycycle_1, dutycycle_2, dutycycle_3;

    if (bldc_phase[motor_idx] % 6 == 0) {
      dutycycle_1 = max_duty;
      dutycycle_2 = 0;
      dutycycle_3 = max_duty - phase[motor_idx];
    }
    else if (bldc_phase[motor_idx] % 6 == 1) {
      dutycycle_1 = max_duty;
      dutycycle_2 = phase[motor_idx];
      dutycycle_3 = 0;
    }
    else if (bldc_phase[motor_idx] % 6 == 2) {
      dutycycle_1 = max_duty - phase[motor_idx];
      dutycycle_2 = max_duty;
      dutycycle_3 = 0;
    }
    else if (bldc_phase[motor_idx] % 6 == 3) {
      dutycycle_1 = 0;
      dutycycle_2 = max_duty;
      dutycycle_3 = phase[motor_idx];
    }
    else if (bldc_phase[motor_idx] % 6 == 4) {
      dutycycle_1 = 0;
      dutycycle_2 = max_duty - phase[motor_idx];
      dutycycle_3 = max_duty;
    }
    else if (bldc_phase[motor_idx] % 6 == 5) {
      dutycycle_1 = phase[motor_idx];
      dutycycle_2 = 0;
      dutycycle_3 = max_duty;
    }

    dutycycle_1 = max(40, dutycycle_1);
    dutycycle_2 = max(40, dutycycle_2);
    dutycycle_3 = max(40, dutycycle_3);

    ledcWrite(m1_pwm_a[motor_idx], dutycycle_1);
    ledcWrite(m1_pwm_b[motor_idx], dutycycle_2);
    ledcWrite(m1_pwm_c[motor_idx], dutycycle_3);
  }
}


void start_calibration(size_t motor_idx) {
  is_calibrated[motor_idx] = 0;
  target_n_steps[motor_idx] = 0;
  step[motor_idx] = CALIBRATION_STEPSIZE;
  prev_photo_interruptor_pin[motor_idx] = analogRead(photo_interruptor_pin[motor_idx]) > 512 ? 1 : 0;
  photo_interruptor_angle[motor_idx] = 0;
  mode[motor_idx] = MODE_CALIBRATE_INIT;
}


void setup() {
  delay_ = 0;
  #ifdef SERIAL_DEBUG
  Serial.begin(115200);
  Serial.print("Begin setup()");
  #endif

  // configure LED PWM functionalitites
  ledcSetup(m1_pwm_a[0], freq, resolution);
  ledcSetup(m1_pwm_b[0], freq, resolution);
  ledcSetup(m1_pwm_c[0], freq, resolution);

  ledcSetup(m1_pwm_a[1], freq, resolution);
  ledcSetup(m1_pwm_b[1], freq, resolution);
  ledcSetup(m1_pwm_c[1], freq, resolution);

  // attach the channel to the GPIO to be controlled
  ledcAttachPin(m1_pwm_a_pin, m1_pwm_a[0]);
  ledcAttachPin(m1_pwm_b_pin, m1_pwm_b[0]);
  ledcAttachPin(m1_pwm_c_pin, m1_pwm_c[0]);

  ledcAttachPin(m2_pwm_a_pin, m1_pwm_a[1]);
  ledcAttachPin(m2_pwm_b_pin, m1_pwm_b[1]);
  ledcAttachPin(m2_pwm_c_pin, m1_pwm_c[1]);

  digitalWrite(m1_en_a_pin, LOW);
  pinMode(m1_en_a_pin, OUTPUT);
  digitalWrite(m1_en_a_pin, HIGH);

  digitalWrite(m1_en_b_pin, LOW);
  pinMode(m1_en_b_pin, OUTPUT);
  digitalWrite(m1_en_b_pin, HIGH);

  digitalWrite(m1_en_c_pin, LOW);
  pinMode(m1_en_c_pin, OUTPUT);
  digitalWrite(m1_en_c_pin, HIGH);

  digitalWrite(m2_en_a_pin, LOW);
  pinMode(m2_en_a_pin, OUTPUT);
  digitalWrite(m2_en_a_pin, HIGH);

  digitalWrite(m2_en_b_pin, LOW);
  pinMode(m2_en_b_pin, OUTPUT);
  digitalWrite(m2_en_b_pin, HIGH);

  digitalWrite(m2_en_c_pin, LOW);
  pinMode(m2_en_c_pin, OUTPUT);
  digitalWrite(m2_en_c_pin, HIGH);

  pinMode(photo_interruptor_pin[0], INPUT_PULLUP);
  pinMode(photo_interruptor_pin[1], INPUT_PULLUP);
  pinMode(go_to_zero_pin, INPUT_PULLUP);

  mode[0] = MODE_STOPPED;
  mode[1] = MODE_STOPPED;

  // slow start of the motors
  for (uint32_t i = 0; i < max_duty; i += 16) {
    for (uint8_t motor_idx = 0; motor_idx < n_motors; ++motor_idx) {
      ledcWrite(m1_pwm_a[motor_idx], i);
      ledcWrite(m1_pwm_c[motor_idx], i);
    }
    delay(1);
  }

  timer = timerBegin(0, 80, true); // 80 MHz / 80 = 1/us
  timerAttachInterrupt(timer, &onTimer, true);
  timerAlarmWrite(timer, SLOWEST_SPEED_TIMER_VAL, true); // timer trigger value; set auto-reload
  timerAlarmEnable(timer);

  delay(1000); // wait for initial transient after power on


  #ifdef SERIAL_DEBUG
  Serial.print("start_calibration()");
  #endif

  for (uint8_t motor_idx = 0; motor_idx < n_motors; ++motor_idx) {
    start_calibration(motor_idx);
  }

  #ifdef SERIAL_DEBUG
  Serial.print("init_spi_slave()");
  #endif

  init_spi_slave();
}


void move_to_step(uint8_t motor_idx, uint32_t target, uint8_t direction, unsigned int min_stepsize) {
  #ifdef SERIAL_DEBUG
  Serial.println();
  Serial.print("Move motor ");
  Serial.print(motor_idx);
  Serial.print(" to target step: ");
  Serial.println(target);
  #endif

  target = (max_n_steps + target + photo_interruptor_angle[motor_idx]) % max_n_steps;

  // stop the motor as late as possible (before reading ``current_step``)
  mode[motor_idx] = MODE_STOPPED;

  const uint32_t current_step = phase[motor_idx] + max_duty * (bldc_phase[motor_idx] + n_bldc_phases * sector[motor_idx]);

  if (direction == DIRECTION_AUTO) {
    if (current_step > target) {
      if (current_step > target + (max_n_steps>>1)) {
        direction = DIRECTION_CLOCKWISE;
      }
      else {
        direction = DIRECTION_COUNTERCLOCKWISE;
      }
    }
    else {
      // target > current_step
      if (target > current_step + (max_n_steps>>1)) {
        direction = DIRECTION_COUNTERCLOCKWISE;
      }
      else {
        direction = DIRECTION_CLOCKWISE;
      }
    }
  }
  if (direction == DIRECTION_CLOCKWISE) {
    if (target > current_step) {
      target_n_steps[motor_idx] = target - current_step;
    }
    else {
      if (current_step - target < min_stepsize) {
        target_n_steps[motor_idx] = 0;
      }
      else {
        target_n_steps[motor_idx] = max_n_steps + target - current_step;
      }
    }
  }
  else if (direction == DIRECTION_COUNTERCLOCKWISE) {
    if (target < current_step) {
      target_n_steps[motor_idx] = current_step - target;
    }
    else {
      // target >= current_step
      if (target - current_step < min_stepsize) {
        target_n_steps[motor_idx] = 0;
      }
      else {
        target_n_steps[motor_idx] = max_n_steps + current_step - target;
      }
    }
  }

  if (direction == DIRECTION_COUNTERCLOCKWISE) {
    step[motor_idx] = -min_stepsize;
  }
  else {
    step[motor_idx] = min_stepsize;
  }

  #ifdef SERIAL_DEBUG
  Serial.print(", current step: ");
  Serial.print(current_step);
  Serial.print(", max_n_steps: ");
  Serial.print(max_n_steps);
  Serial.print(", calibration step: ");
  Serial.print(photo_interruptor_angle[motor_idx]);
  Serial.print(", direction: ");
  Serial.print(direction);
  Serial.print(", stepping by n_steps: ");
  Serial.print(target_n_steps[motor_idx]);
  Serial.print(", One step is: ");
  Serial.print(step[motor_idx]);
  Serial.println();
  #endif

  mode[motor_idx] = MODE_BALLISTIC_MOVEMENT;
}


void loop() {

#ifdef SERIAL_DEBUG
  for (uint8_t motor_idx = 0; motor_idx < n_motors; ++motor_idx) {
    Serial.print("Motor ");
    Serial.print(motor_idx);
    Serial.print(": phase = ");
    Serial.print(phase[motor_idx] + max_duty * (bldc_phase[motor_idx] + n_bldc_phases * sector[motor_idx]));
    Serial.print(": mode = ");
    Serial.print(mode[motor_idx]);
    Serial.println();
  }
#endif

  delay(100);

  if (!digitalRead(go_to_zero_pin) && mode[0] == MODE_STOPPED && mode[1] == MODE_STOPPED) {
    #ifdef SERIAL_DEBUG
    Serial.println("Go to zero asserted and motors are stopped.");
    #endif
    move_to_step(0, 0, DIRECTION_CLOCKWISE, CALIBRATION_STEPSIZE);
    move_to_step(1, 0, DIRECTION_COUNTERCLOCKWISE, CALIBRATION_STEPSIZE);
    return;
  }

  if (mode[0] == MODE_CALIBRATE_INIT || mode[1] == MODE_CALIBRATE_INIT) {
    // still calibrating
    return;
  }

  sprintf(sendbuf, "This is the receiver, sending data for transmission number %04d.", delay_);
  spi_slave_free(RCV_HOST);
  init_spi_slave();
  spi_slave_transaction_t t;
  memset(&t, 0, sizeof(t));
  memset(recvbuf, 0xA5, 8);

  // set up transaction
  t.length=12*8;
  t.tx_buffer=sendbuf;
  t.rx_buffer=recvbuf;

  esp_err_t ret = spi_slave_transmit(RCV_HOST, &t, portMAX_DELAY);

  // spi_slave_transmit does not return until the master has done a transmission, so by here we have sent our data and received data from the master
  #ifdef SERIAL_DEBUG
  Serial.print("SPI transfer return code: ");
  Serial.print(ret);
  Serial.print(", received data: ");
  for (uint8_t foo = 0; foo < 12; ++foo) {
    Serial.printf("%d ", recvbuf[foo]);
  }
  Serial.println();
  #endif

  if (ret == 0) {
    uint32_t target_phase_m1 = recvbuf[0] + (recvbuf[1] << 8) + (recvbuf[2] << 16) + (recvbuf[3] << 24);
    uint8_t stepsize_m1 = recvbuf[4];
    uint8_t direction_m1 = recvbuf[5];

    #ifdef SERIAL_DEBUG
    Serial.print("SPI command: m1 moving to phase ");
    Serial.print(target_phase_m1);
    Serial.print(", stepsize = ");
    Serial.print(stepsize_m1);
    Serial.print(", direction = ");
    Serial.print(direction_m1);
    Serial.println();
    #endif

    uint32_t target_phase_m2 = recvbuf[0 + 6] + (recvbuf[1 + 6] << 8) + (recvbuf[2 + 6] << 16) + (recvbuf[3 + 6] << 24);
    uint8_t stepsize_m2 = recvbuf[4 + 6];
    uint8_t direction_m2 = recvbuf[5 + 6];
    #ifdef SERIAL_DEBUG
    Serial.print("SPI command: m2 moving to phase ");
    Serial.print(target_phase_m2);
    Serial.print(", stepsize = ");
    Serial.print(stepsize_m2);
    Serial.print(", direction = ");
    Serial.print(direction_m2);
    Serial.println();
    #endif

    target_phase_m1 = min(target_phase_m1, max_n_steps);
    target_phase_m2 = min(target_phase_m2, max_n_steps);

    move_to_step(0, target_phase_m1, direction_m1, stepsize_m1);
    move_to_step(1, target_phase_m2, direction_m2, stepsize_m2);
  }


  // // autonomous movement demo
  // ++delay_;
  // if (delay_ > 5 && delay_ <= 10) {
  //   move_to_step(0, 0, DIRECTION_CLOCKWISE, 4*CALIBRATION_STEPSIZE);
  //   move_to_step(1, 0, DIRECTION_CLOCKWISE, 4*CALIBRATION_STEPSIZE); // slowest possible!
  //   Serial.println("0");
  // }
  // else if (delay_ > 10 && delay_ <= 15) {
  //   move_to_step(0, max_n_steps >> 2, DIRECTION_CLOCKWISE, 2*CALIBRATION_STEPSIZE);
  //   move_to_step(1, max_n_steps >> 2, DIRECTION_CLOCKWISE, CALIBRATION_STEPSIZE); // slowest possible!
  //   Serial.println("90");
  // }
  // else if (delay_ > 15 && delay_ <= 20) {
  //   move_to_step(0, max_n_steps >> 1, DIRECTION_CLOCKWISE, 2*CALIBRATION_STEPSIZE);
  //   move_to_step(1, max_n_steps >> 1, DIRECTION_CLOCKWISE, CALIBRATION_STEPSIZE); // slowest possible!
  //   Serial.println("180");
  // }
  // else if (delay_ > 25) {
  //   move_to_step(0, (max_n_steps >> 2) + (max_n_steps >> 1), DIRECTION_CLOCKWISE, 2*CALIBRATION_STEPSIZE);
  //   move_to_step(1, (max_n_steps >> 2) + (max_n_steps >> 1), DIRECTION_CLOCKWISE, CALIBRATION_STEPSIZE); // slowest possible!
  //   Serial.println("270");
  //   delay_ = 0;
  // }
}

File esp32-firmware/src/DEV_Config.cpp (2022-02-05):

/*****************************************************************************
* | File      	:   DEV_Config.c
* | Author      :   Waveshare team
* | Function    :   Hardware underlying interface
* | Info        :
*----------------
* |	This version:   V1.0
* | Date        :   2020-02-19
* | Info        :
#
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
******************************************************************************/
#include "DEV_Config.h"

void GPIO_Config(void)
{
    pinMode(EPD_BUSY_PIN,  INPUT);
    pinMode(EPD_RST_PIN , OUTPUT);
    pinMode(EPD_DC_PIN  , OUTPUT);

    pinMode(EPD_SCK_PIN, OUTPUT);
    pinMode(EPD_MOSI_PIN, OUTPUT);
    pinMode(EPD_CS_PIN , OUTPUT);

    digitalWrite(EPD_CS_PIN , HIGH);
    digitalWrite(EPD_SCK_PIN, LOW);
}
/******************************************************************************
function:	Module Initialize, the BCM2835 library and initialize the pins, SPI protocol
parameter:
Info:
******************************************************************************/
UBYTE DEV_Module_Init(void)
{
	//gpio
	GPIO_Config();

	//serial printf
	//Serial.begin(115200);

	// spi
	// SPI.setDataMode(SPI_MODE0);
	// SPI.setBitOrder(MSBFIRST);
	// SPI.setClockDivider(SPI_CLOCK_DIV4);
	// SPI.begin();

	return 0;
}

/******************************************************************************
function:
			SPI read and write
******************************************************************************/
void DEV_SPI_WriteByte(UBYTE data)
{
    //SPI.beginTransaction(spi_settings);
    digitalWrite(EPD_CS_PIN, GPIO_PIN_RESET);

    for (int i = 0; i < 8; i++)
    {
        if ((data & 0x80) == 0) digitalWrite(EPD_MOSI_PIN, GPIO_PIN_RESET);
        else                    digitalWrite(EPD_MOSI_PIN, GPIO_PIN_SET);

        data <<= 1;
        digitalWrite(EPD_SCK_PIN, GPIO_PIN_SET);
        digitalWrite(EPD_SCK_PIN, GPIO_PIN_RESET);
    }

    //SPI.transfer(data);
    digitalWrite(EPD_CS_PIN, GPIO_PIN_SET);
    //SPI.endTransaction();
}

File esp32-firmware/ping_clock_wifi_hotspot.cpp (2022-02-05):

#define ASYNC_TCP_SSL_ENABLED 0

#include <stdint.h>
#include <Arduino.h>

#define CAPTIVE_PORTAL
#include <EEPROM.h>
#include <WiFi.h>
#include <ESP32Ping.h>
#include <DNSServer.h>
#include <AsyncTCP.h>
#include "ESPAsyncWebServer.h"
#include "driver/spi_master.h"
#include "driver/spi_common.h"

#include "EPD.h"
#include "GUI_Paint.h"

#include "log2fix/log2fix.h"

#define MIN(a,b) ((a) < (b) ? (a) : (b))
#define MAX(a,b) ((a) > (b) ? (a) : (b))


/**
 * EPD
**/

#define GPIO_HANDSHAKE 2
#define GPIO_MOSI 12
#define GPIO_MISO 13
#define GPIO_SCLK 15
#define GPIO_CS 14

UBYTE BlackImage[100*480];

volatile uint8_t display_refresh_delay_ = 0;


/**
 * precision for fixed-point numbers (16.16 unsigned)
**/

#define PRECISION 16


/**
 * global state of the pings and motor angles
**/

volatile uint32_t ping_ms;	   // fixed point number
volatile uint32_t avg_ping_ms;   // fixed point number
volatile uint32_t m1_step;
volatile uint32_t m2_step;

volatile unsigned int target_phase_m1;
volatile unsigned int target_phase_m2;
const unsigned int m1_direction = 2;
const unsigned int m2_direction = 2;
const unsigned int phase_m1_offset = 7500ul;
const unsigned int phase_m2_offset = 164400ul;
const unsigned int stepsize_fast = 48;
const unsigned int stepsize_slow = 1;

const uint32_t small_section_angle = 7500ul;
const uint32_t large_section_angle = 113500ul;


/**
 * SPI bus
**/

#define SPI_CS_PIN  5
#define SPI_CLK_PIN 18
#define SPI_MOSI_PIN 23

spi_device_handle_t spi;


/**
 * wifi
**/

volatile int prev_wifi_status;

#define WIFI_AP_SSID "ping-clock"

String ssid = "";
String password = "";
String host_to_ping = "";

#define HTTP_PORT 80
#define MESSAGE_MAX_LEN 256

char messageBuf[MESSAGE_MAX_LEN];

const char HTTP_HEAD_HTML[] PROGMEM = "<!DOCTYPE HTML><html><head><meta name = \"viewport\" http-equiv=\"content-type\" content = \"width = device-width, initial-scale = 1.0, maximum-scale = 1.0, user-scalable=0\"><title>ESP32 Demo</title>";
const char HTTP_STYLE[] PROGMEM= "<style>body { background-color: #0067B3  ; font-family: Arial, Helvetica, Sans-Serif; Color: #FFFFFF; }</style></head>";
const char HTTP_HEAD_STYLE[] PROGMEM= "<body><center><h1 style=\"color:#FFFFFF; font-family:verdana;font-family: verdana;padding-top: 10px;padding-bottom: 10px;font-size: 36px\">ESP32 Captive Portal</h1><h2 style=\"color:#FFFFFF;font-family: Verdana;font: caption;font-size: 27px;padding-top: 10px;padding-bottom: 10px;\">Give Your WiFi Credentials</h2>";
const char HTTP_FORM_START[] PROGMEM= "<FORM action=\"/\" method= \"post\">";
const char HTTP_CONTENT1_START[] PROGMEM= "<div style=\"padding-left:100px;text-align:left;display:inline-block;min-width:150px;\"><a href=\"#pass\" onclick=\"c(this)\" style=\"text-align:left\">{v}</a></div>&nbsp&nbsp&nbsp <div style=\"display:inline-block;min-width:260px;\"><span class=\"q\" style=\"text-align:right\">{r}%</span></div><br>";
const char HTTP_CONTENT2_START[] PROGMEM= "<P ><label style=\"font-family:Times New Roman\">SSID</label><br><input maxlength=\"30px\" id=\"ssid\" type=\"text\" name=\"ssid\" placeholder='Enter WiFi SSID' style=\"width: 400px; padding: 5px 10px ; margin: 8px 0; border : 2px solid #3498db; border-radius: 4px; box-sizing:border-box\" ><br></P>";
const char HTTP_CONTENT3_START[] PROGMEM= "<P><label style=\"font-family:Times New Roman\">PASSKEY</label><br><input maxlength=\"30px\" type = \"text\" id=\"pass\" name=\"passkey\"  placeholder = \"Enter WiFi PASSKEY\" style=\"width: 400px; padding: 5px 10px ; margin: 8px 0; border : 2px solid #3498db; border-radius: 4px; box-sizing:border-box\" ><br><P>";
const char HTTP_CONTENT4_START[] PROGMEM= "<input type=\"checkbox\" name=\"configure\" value=\"change\"> Change IP Settings </P>";
const char HTTP_CONTENT5_START[] PROGMEM= "<INPUT type=\"submit\">&nbsp&nbsp&nbsp&nbsp<INPUT type=\"reset\"><style>input[type=\"reset\"]{background-color: #3498DB; border: none; color: white; padding:  15px 48px; text-align: center; text-decoration: none;display: inline-block; font-size: 16px;}input[type=\"submit\"]{background-color: #3498DB; border: none; color: white; padding:  15px 48px;text-align: center; text-decoration: none;display: inline-block;font-size: 16px;}</style>";
const char HTTP_FORM_END[] PROGMEM= "</FORM>";
const char HTTP_SCRIPT[] PROGMEM= "<script>function c(l){document.getElementById('ssid').value=l.innerText||l.textContent;document.getElementById('pass').focus();}</script>";
const char HTTP_END[] PROGMEM= "</body></html>";

const char* messageStatic PROGMEM= "{\"staticSet\":\"staticValue\", \"staticIP\":\"%s\", \"staticGate\":\"%s\", \"staticSub\":\"%s\",\"ssidStatic\":\"%s\",\"staticPass\":\"%s\"}";
const char* messageDhcp PROGMEM= "{\"dhcpSet\":\"dhcpValue\",\"ssidDHCP\":\"%s\", \"passDHCP\":\"%s\"}";

const char HTTP_PAGE_STATIC[] PROGMEM = "<p>{s}<br>{g}<br>{n}<br></p>";
const char HTTP_PAGE_DHCP[] PROGMEM = "<p>{s}</p>";
const char HTTP_PAGE_WiFi[] PROGMEM = "<p>{s}<br>{p}</p>";
const char HTTP_PAGE_GOHOME[] PROGMEM = "<H2><a href=\"/\">go home</a></H2><br>";
const char HTTP_PAGE_HOME[] PROGMEM = "<H2>HELLO, WORLD</H2><br>";

DNSServer dnsServer;
AsyncWebServer server(HTTP_PORT);


/**
 * global state
**/

hw_timer_t * timer = NULL;


// ---------------------------------------------------------------------------


/**
 * EEPROM functions
**/

String read_string(int l, int p){
	String temp;
	for (int n = p; n < l+p; ++n) {
		if (char(EEPROM.read(n)) != '\0') {
			temp += String(char(EEPROM.read(n)));
		}
		else {
			n = l + p;
		}
	}
	return temp;
}

String read_prom_host_to_ping() {
	return read_string(30, 60);
}

void write_EEPROM(String s, int pos){
	for (int n = pos; n < s.length()+pos; ++n){
		EEPROM.write(n,s[n-pos]);
	}
}

void ROMwrite(String s, String p,String host_to_ping){
	write_EEPROM(s + '\0', 0);
	write_EEPROM(p + '\0', 30);
	write_EEPROM(host_to_ping + '\0', 60);
	EEPROM.commit();
}


/**
 * web server
**/

void handleNotFound(AsyncWebServerRequest *);
void handleStaticForm(AsyncWebServerRequest *);

class CaptiveRequestHandler : public AsyncWebHandler {
public:
  CaptiveRequestHandler() {}
  virtual ~CaptiveRequestHandler() {}

  bool canHandle(AsyncWebServerRequest *request){
	//request->addInterestingHeader("ANY");
	return true;
  }

  void handleRequest(AsyncWebServerRequest *request) {
	Serial.println("in handleRequest(), redirecting");
	request->redirect("http://" + WiFi.softAPIP().toString() + "/");
  }
};

void handleNotFound(AsyncWebServerRequest *request)
{
  String message = "File Not Found\n\n";
  message += "URI: ";
  message += request->url();
  request->send_P(404, "text/plain", message.c_str());
}
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
